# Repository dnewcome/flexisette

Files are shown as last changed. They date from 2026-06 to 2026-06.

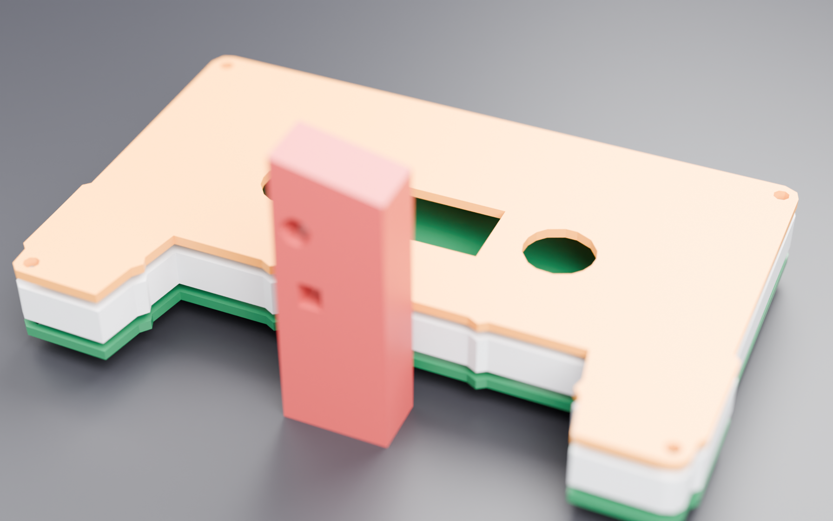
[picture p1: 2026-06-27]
render/out/flexisette_assembly.png

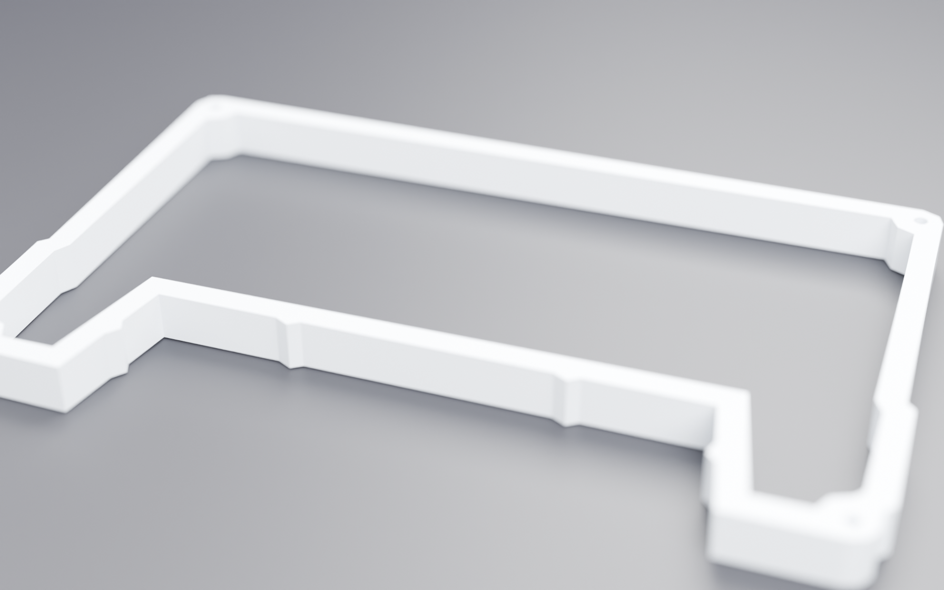
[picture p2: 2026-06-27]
render/out/flexisette_frame.png

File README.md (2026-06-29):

# flexisette

A **flex-PCB cassette-tape multimedia object** — a parametric, cassette-shaped board that plays its
own music with a tiny animated display where the tape window would be. Designed as reproducible
"drops": the whole thing regenerates from source (CAD, PCB, renders, firmware).

> Status: work in progress. The mechanical CAD and the PCB design are functional and fabbable; the
> on-device firmware is early.

## The idea

It's the size and shape of a compact cassette. A **0.96″ OLED** sits behind the cassette's central
**tape window** and plays a looping tape-winding animation — the one spot on a cassette where you
expect to see motion. An **ESP32-S3** plays the baked-in audio out a small speaker; it charges over
USB-C and runs off a LiPo.

| Block | Part |
|---|---|
| MCU | ESP32-S3-WROOM-1-N16R8 (native USB) |
| Display | 0.96″ SSD1306 OLED (I²C), in the tape window |
| Audio | MAX98357A I²S class-D amp → speaker |
| Power | USB-C → TP4056 charger → LiPo → ME6211 3V3 |

All parts are JLCPCB/LCSC-stocked for turnkey assembly.

## Repository layout

```
cad/        parametric CAD (build123d) of the physical parts — frame, panel, insert, spacer —
            extracted from real vendor cassette STLs; mate-based assembly + MuJoCo sim
pcb/        the electronics PCB, code-driven with tscircuit (modules/ -> index.circuit.tsx),
            finished in KiCad. Includes the encoded place->route->measure tooling (scripts/)
            and per-fab DRC rule files (rules/)
display/    the 128x64 tape-winding animation for the OLED (display/tape_anim.py)
render/     Blender product renders / .blend files
assets/     vendor cassette shell STLs the CAD is derived from (see assets/DOWNLOADS.md for sources)
specs/      design specs
PARTS.md    component sourcing / BOM notes
```

## Building

- **CAD:** `make` (or run the `cad/*.py` build123d scripts) → STL/STEP/FCStd in `cad/build/`.
- **PCB:** in `pcb/`, `npm install` then `make build` (tscircuit) → `index.circuit.kicad_pcb`; place
  with `make outline` / `make routecheck`, route with Freerouting (`make freeroute`) or in KiCad, and
  apply a fab rule set from `pcb/rules/`. The board outline is the real cassette face (derived from the
  same profile as the CAD).
- **Animation:** `python3 display/tape_anim.py` → a 128×64 GIF preview.

The PCB workflow follows the code-driven, placement-first approach (modular subcircuits, deterministic
placement, ground pours, then route) — see [docs/pcb-toolchain.md](docs/pcb-toolchain.md) and
[docs/workflows.md](docs/workflows.md).

## Documentation

Full documentation lives in **[`docs/`](docs/)** — start with
**[docs/architecture.md](docs/architecture.md)** for the big picture, then:

- [PCB toolchain](docs/pcb-toolchain.md) · [Placement (the fast loop)](docs/placement.md) ·
  [CAD enclosure](docs/cad-enclosure.md)
- [3D fit-check + renders](docs/3d-fit-and-renders.md) · [Fabrication (JLCPCB)](docs/fabrication.md)
- [Workflows — task recipes](docs/workflows.md) · [Reference — every target/script/artifact](docs/reference.md)
- [Roadmap & known issues](docs/roadmap.md) · [Planned placement constraints](docs/placement-constraints.md)

*Project started June 25, 2026.*

## License

TBD. Vendor cassette assets under `assets/` retain their original licenses — see
`assets/DOWNLOADS.md` for attribution.

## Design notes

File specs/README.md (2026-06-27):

# flexisette — Form-Factor Specs

Four construction options for the same product. They **share one frozen electrical engine** (see [`../PARTS.md`](../PARTS.md)) — what differs is the *physical build*. The discipline throughout: **freeze the electronics, vary the cosmetics + content**, so a "drop" is cheap.

> A cassette is **~100.5 × 64 × 12 mm**. The Norelco case + a paper (or flex) J-card is the package. The engine BOM is one line:
> ESP32-S3-WROOM-1-N16R8 · 1.91" RM67162 QSPI AMOLED · MAX98357A+speaker / PCM5102A+jack · microSD or W25Q512 · NTAG I²C plus · LP503562 1200mAh · MCP73831 + USB-C native.

## The four

| # | Name | Form | Boards | Thickness | Plays in a real deck? | Battery / runtime | Per-drop cost | Best for |
|---|---|---|---|---|---|---|---|---|
| [A](A-the-deck.md) | **The Deck** | full cassette | 2 rigid + 3D-printed spacers | ~12 mm | ✅ **yes** | 1200 mAh / ~7–9 h | medium | the full "it really plays in a tape deck" object |
| [B](B-the-slim.md) | **The Slim** | cassette outline | 1 rigid | ~5–7 mm | ✖ (needs a carrier) | 500 mAh / ~3 h | high (whole-board respin) | elegant ultra-thin PCB-as-art player |
| [C](C-the-flex.md) | **The Flex** | cassette, flex/rigid-flex | rigid islands + flex | thin–12 mm | partial | island-dependent | high fab | the most distinctive substrate; original "flex cassette" vision |
| [D](D-flex-jcard.md) | **The Flex J-card** | J-card insert | 1 plain flex | <0.5 mm folded | n/a (it's the insert) | none (or NFC-harvest) | **very low (~$1–3)** | the per-drop art/NFC layer — pairs with A/B/C |

## How they relate
- **A, B, C are mutually exclusive device bodies** — pick one to build.
- **D is not a competitor — it's the per-drop skin.** The flex J-card (D) is the cheap, swappable art + NFC + touch layer that any of A/B/C uses as its insert/front. It *is* the parametric mechanism; A/B/C are just how deep the electronics go behind it.
- **Recommended first build:** prototype the engine on a breadboard (the "first slice"), then realize it as **A (The Deck)** — it's the only one that delivers the tape-deck-playback payoff — with **D** as its art layer. B and C are alternate editions to explore later.

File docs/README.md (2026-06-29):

# flexisette documentation

Start with **[architecture.md](architecture.md)** for the big picture, then dive into a subsystem.

| Doc | What it covers |
|---|---|
| **[architecture.md](architecture.md)** | The whole system: the three subsystems (PCB / placement / CAD), the fit-check seam, the data flow, the four coordinate frames, the repo map, and the reproducibility principles. **Read first.** |
| [pcb-toolchain.md](pcb-toolchain.md) | The board: modular `<subcircuit>` architecture, the parts/nets/cutouts, and the tscircuit→KiCad place→route→IPC-inject pipeline (`route.sh` + helpers). |
| [placement.md](placement.md) | The fast early-design loop: positions-as-data, the `place`/`sync`/`variant` round-trip, the auto-untangle (rotation), block autoplace, the placement gates, and the planned constraint layer. |
| [cad-enclosure.md](cad-enclosure.md) | The 3D-printed cassette shell (build123d): the sandwich stack, `machine_params.py`, each part, the head insert + screw bosses, and the assembly. |
| [3d-fit-and-renders.md](3d-fit-and-renders.md) | The seam + the pictures: bare vs populated board into 3D, the coordinate transforms, the OLED model, the OpenSCAD fit-check, the GLB merge, and the Blender beauty render. |
| [fabrication.md](fabrication.md) | Gerbers + assembly BOM/CPL (`make fab`), uploading to JLCPCB, and what the DFM does/doesn't catch. |
| [workflows.md](workflows.md) | Task recipes — copy-paste commands for the common things (route, fab, variant, fit-check, render, see the files). |
| [reference.md](reference.md) | Exhaustive reference: every make target, every script, every generated artifact, every data-file format. |
| [roadmap.md](roadmap.md) | Known gaps + discrepancies + the (grounded) future-work directions. |
| [placement-constraints.md](placement-constraints.md) | Design (plan only) for the per-part lock / move / rotate constraint layer. |

## Orientation for a newcomer

- The object is a **cassette-shaped PCB** in a **3D-printed cassette shell**, with an OLED behind the
  tape window. It regenerates entirely from source — see *reproducibility principles* in
  [architecture.md](architecture.md).
- **PCB work** is in `pcb/` (run make targets from there); **mechanical CAD** is in `cad/` (run from the
  repo root). The two meet in the **3D fit-check** (`make fit`).
- If you just want to *see* the current design: `cd pcb && make show`, or `make fit` then open
  `cad/build/fit_iso.png`.
- If something says "where's the file?" — generated artifacts live in **gitignored `build/`/`dist/`/`fab/`**
  dirs (real files, not committed); the map is in [reference.md](reference.md).

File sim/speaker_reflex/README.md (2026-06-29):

# speaker_reflex — sealed face-firing micro-speaker sim

Thiele-Small lumped **acoustical equivalent circuit** of the flexisette speaker. The design (decided):
a slim **face-firing micro-driver** in a **sealed** back-volume carved from the cassette interior — the
cassette is only 9mm thick, so a forward-firing driver through the head slot doesn't fit; lying flat and
firing out the face does. (The model still supports a vented port; we A/B'd it and chose sealed.)

The enclosure *is* the model: the box is an acoustic compliance `Cab = Vb/ρc²`. ngspice solves the
circuit; an independent numpy complex-impedance solve verifies the deck.

```
python3 reflex.py        # -> sealed.png (SPL vs Vb, excursion, Fc&Qtc vs Vb, impedance), reflex.cir
```

**Driver: PUI Audio AS01808AO** (18×13mm, 3mm thick, 8Ω, 1W). `Fs=320 Hz` and impedance are PUBLISHED;
`Sd, Vas, Qts, Xmax` are **ESTIMATED from the cone size — measure before finalizing** (a DATS, or a DIY
two-resistor impedance sweep on the board's own amp). The whole "boomy vs flat" question hangs on Qts.

## Verification
- sealed ngspice vs analytic |Ud|: **0.00 %**.
- sealed impedance = single hump (vs the vented twin-hump we confirmed earlier).

## Findings (AS01808, estimated Vas/Qts)
1. **The real driver's low Fs (320 Hz) drops the box knee to ~450–550 Hz** — a genuine low-mid lift,
   far below the 1.1 kHz of the pessimistic placeholder. Sealed in the cassette gives real low-mids.
2. **Qtc is high (~1.3–2.0)** with the estimated `Qts=1.0` → a resonant **peak/boom at Fc**, not a flat
   response. The *real* Qts decides whether that's a pleasant bump or a one-note boom — **measure it.**
   If it's high, a touch of stuffing (raises effective Vb, lowers Qtc) or a lower-Qts driver tames it.
3. **More back-volume always helps** (lower Fc *and* lower Qtc) — `Fc 640→413 Hz` and `Qtc 2.0→1.3` as
   `Vb 4→18 cm³`. **Carve as much interior as possible** (~10–12 cm³ → Fc ~450 Hz); diminishing past that.
4. **Excursion-limited, not power-limited:** ~0.7 mm @1W vs ~0.35 mm Xmax → ~**250 mW clean → ~70 dB@1m**.
   The MAX98357A has headroom the micro driver can't use. (Absolute SPL is uncertain on estimates.)

## Next
- **Measure the AS01808's T-S** (Qts especially) and re-run → lock the response / decide if stuffing is
  needed. The DIY rig: drive the driver through a known series R off the board's amp, log V across each,
  derive Z(f) → Fs, Qts (added-mass trick for Vas).
- **CAD the sealed chamber** (build123d) behind the face-firing driver, sealing as much cassette
  interior as the PCB/battery allow as back-volume; the driver lies flat (3mm) under a grille.

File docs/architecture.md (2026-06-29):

# flexisette — architecture

How the whole thing fits together. Start here; the subsystem docs go deep.

## What it is

flexisette is a **flex-PCB cassette-tape multimedia object**: a board the size and shape of a compact
cassette that plays its own baked-in music out a small speaker while a 0.96″ OLED animates where the
tape window would be. ESP32-S3 brain, USB-C charging, LiPo power. It lives inside a **3D-printed
cassette shell**, and the OLED glows through the shell's central window.

**North star — reproducible "drops":** the entire object regenerates from source. The circuit, the
board placement, the routing inputs, the enclosure parts, the fab outputs, and the renders are all
produced by code + data in this repo. Shipping a different version is editing data, not redrawing.

## The three subsystems + the seam

```
        ┌──────────────────────────────┐        ┌──────────────────────────────┐
        │  PCB  (electronics)          │        │  CAD  (mechanical)           │
        │  code-driven, pcb/           │        │  parametric, cad/            │
        │                              │        │                              │
        │  tscircuit .tsx  ──► KiCad   │        │  build123d .py  ──► STL/STEP │
        │  generate + place   route    │        │  shell: frame/panel/insert/  │
        │                              │        │         spacer  +  assembly  │
        └───────────────┬──────────────┘        └───────────────┬──────────────┘
                        │                                        │
                        │     shared geometry: cassette outline, │
                        │     tape window, 2 reels, 4 screw holes │
                        ▼                                        ▼
              ┌─────────────────────────────────────────────────────────┐
              │  SEAM: the 3D fit-check  (cad/import_pcb + render_fit)   │
              │  bring the routed board INTO the printed-part assembly,  │
              │  co-register, render, gate placement on alignment       │
              └─────────────────────────────────────────────────────────┘
                        │
                        ▼
        ┌──────────────────────────────┐        ┌──────────────────────────────┐
        │  Firmware (display/, early)  │        │  Outputs                     │
        │  tape-winding animation      │        │  fab (gerbers/BOM/CPL),      │
        │  on the SSD1306              │        │  renders (OpenSCAD + Blender)│
        └──────────────────────────────┘        └──────────────────────────────┘
```

- **PCB** — [pcb-toolchain.md](pcb-toolchain.md): tscircuit (React/TSX) *generates + places* the board
  from code; KiCad *routes* it (the autorouter via Freerouting, injected back over the IPC API). The
  north-star belief is **routing difficulty is set by placement**, so the effort goes into placement.
- **Placement** — [placement.md](placement.md): the fast early-design loop. Positions live as **data**
  (`pcb/placement/<variant>.json`), round-trip between KiCad and the source, get auto-untangled by a
  rotation pass, and drive per-release **variants**.
- **CAD enclosure** — [cad-enclosure.md](cad-enclosure.md): the printed cassette shell as a build123d
  sandwich (PCB-half + spacer + PCB-half ≈ 9 mm), with the head-access insert, screw bosses, and the
  window/reel/screw features that must line up with the board.
- **3D fit + renders** — [3d-fit-and-renders.md](3d-fit-and-renders.md): the seam. Export the board to
  3D (bare KiCad STL or populated tscircuit GLB), seat it in the shell assembly, render the fit-check
  (OpenSCAD) or a beauty shot (Blender). The OLED — which has no CDN 3D model — is modeled here.
- **Fabrication** — [fabrication.md](fabrication.md): Gerbers + drill + assembly BOM/CPL for JLCPCB, and
  what their DFM does and doesn't catch.
- **Reference** — [reference.md](reference.md): every make target, script, artifact, and data file.
- **Workflows** — [workflows.md](workflows.md): task recipes. **Roadmap + known issues** —
  [roadmap.md](roadmap.md). **Planned constraint layer** — [placement-constraints.md](placement-constraints.md).

## Data flow (source → object)

```
SOURCE (committed)                 GENERATED (gitignored build/)        OUTPUT
─────────────────                  ────────────────────────────         ──────
pcb/*.circuit.tsx  ──tsci export──► pcb/index.circuit.kicad_pcb ──route──► fab/  (gerbers, BOM, CPL)
pcb/placement/*.json ──apply──────►  (placement on the board)
                                    pcb/build/3d/*.glb,*.step   ─────────► glTF viewers
cad/*.py           ──build123d────► cad/build/*.stl, *.step    ──render──► cad/build/fit_*.png  (OpenSCAD)
                                                               ──render──► render/out/*.png     (Blender)
```

Everything in `build/`, `dist/`, `fab/` is **regenerated, gitignored, never committed** — real files on
disk you can open, just not in git. The committed source of truth is the `.tsx`, the `.py`, the
`placement/*.json`, and `lib/*.json`. See [reference.md](reference.md) for the full artifact map.

## Coordinate frames (the thing that bites)

Four frames are in play; conversions are the subtle part (full detail in
[3d-fit-and-renders.md](3d-fit-and-renders.md) and [placement.md](placement.md)):

| Frame | Origin / up | Notes |
|---|---|---|
| **tscircuit** (design) | board-centred, **Y-up** | the `.tsx` `pcbX/pcbY`; window at (0, +3) |
| **KiCad** (`.kicad_pcb`) | offset to ≈(100,100), **Y-down** | `tx = kx−100, ty = 100−ky` |
| **cad / OpenSCAD** | board-centred, **Z-up** | build123d parts; fit render frame |
| **glTF (GLB)** | board-centred, **Y-up** (thickness=Y) | tscircuit (x,y) → GLB (x, −z) |

The board-outline bbox centre is what reconciles tscircuit↔KiCad (it's at (100,100) for this board).
KiCad→cad needs a **Y-mirror**; cad→GLB needs a **−90° rotation about X**.

## The repository

```
flexisette/
  README.md, PARTS.md          project overview + bill of materials
  Makefile                     top-level: CAD builds + Blender renders
  cad/                         parametric cassette shell (build123d) + the 3D fit-check + OLED model
  pcb/                         the tscircuit board, its scripts, Makefile, placement data, fab outputs
    modules/                   the functional blocks (mcu/power/audio/display) as <subcircuit>s
    scripts/                   the place→route→fab pipeline (route.sh + the helpers)
    lib/, imports/             fab params, helpers, imported JLC parts, cassette outline/holes JSON
    placement/<variant>.json   positions-as-data (the round-trip floorplan)
    tests/                     unit tests for the placement tooling (autoplace, untangle)
  render/                      Blender beauty-render pipeline (needs a GPU box)
  display/                     firmware-side OLED animation (early)
  docs/                        this documentation set
  assets/                      vendor cassette-shell source files (STL/PDF)
```

## Reproducibility principles

1. **Generate, don't draw.** The board comes from `.tsx`; the shell from `.py`. No hand-placed XML.
2. **Positions are data.** The floorplan lives in `placement/<variant>.json`, round-tripped from KiCad
   — so a layout is reproducible and a *variant is a different data file*, not a forked circuit.
3. **One source of truth per dimension.** `cad/machine_params.py` holds every shared shell dimension;
   parts derive from it. (Caveat: a few values have drifted — see [roadmap.md](roadmap.md).)
4. **The fit-check is a gate, not a picture.** Connector/cutout/screw alignment between board and shell
   is verified in 3D and treated like a DRC rule.
5. **Tools over heroics.** Routing is hard, so design for trivial routing (modular blocks, ground
   pours, deliberate placement, auto-untangle) and hand-finish the tail.

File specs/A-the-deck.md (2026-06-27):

# Spec A — "The Deck" (full-size, 2 rigid boards + 3D-printed spacers)

**One-liner:** A full cassette-dimensioned device — two rigid PCBs sandwiched around a 3D-printed internal frame — that is self-contained *and* can be dropped into a real tape deck and played.

This is the maximal version: most capable, biggest battery, and the only build that delivers the **plays-in-a-real-deck** payoff.

## Dimensions / stack-up
Target envelope: **100.5 × 64 × 12 mm** (compact-cassette nominal). The 12 mm Z budget, front to back:

```
 front board (1.0–1.6 mm) + display module (~2–3 mm, recessed behind window)
 ── 3D-printed spacer frame ── (houses LiPo 5 mm + transmit head + auto-stop gear)
 main board (1.6 mm)
                                              ≈ 11–12 mm total
```

## Boards
- **Front board (per-drop candidate):** display window + AMOLED mount, capacitive-touch pads / tactile buttons, status LEDs, top-copper J-card-style art, speaker grille. Can be a cheap cosmetic respin per drop — *or* leave it minimal and push art onto a flex J-card (Spec D).
- **Main board (frozen engine):** ESP32-S3, audio (MAX98357A + PCM5102A), storage, charger + power, USB-C (native), NFC (NTAG I²C plus), the **tape-head driver amp**, and the board-to-board connector.
- **Interconnect:** Hirose DF40 mezzanine (0.4 mm, pick stack height to fit) or a short FFC between the two boards.

## 3D-printed spacer parts (the heart of this spec)
A printed frame does five jobs at once:
1. Holds the two boards at correct spacing and registration (standoffs/snap features).
2. **LiPo pocket** (LP503562, 5 mm) in the central cavity.
3. **Bottom-edge cassette geometry** — head-access window, capstan holes, pinch-roller cutouts, alignment/registration boss, write-protect notches — so it **loads and seats in a real deck** and in the Norelco case.
4. **Transmit-head mount** at the head window (from a harvested adapter head — see PARTS §11), sprung to the right contact height.
5. **Auto-stop defeat** — a capstan-driven dummy-hub gear so the deck doesn't stop on "no tape motion." (Harvest this whole mechanism from the donor adapter.)

## Tape-deck playability — ✅ yes
This is the variant designed for it. The same audio engine has three output destinations: onboard speaker (MAX98357A), 3.5 mm jack (PCM5102A), and the **transmit head** (line-out → small amp → head). Mono, lo-fi, on-brand.

## Drops / parametric story
Frozen main board + frozen engine BOM. Per drop you vary: the **flex J-card / front-board art**, the **content pack** on storage, and optionally reprint the **spacer** for shape tweaks. The expensive board never respins.

## Pros / cons
- ➕ Most capable; ~7–9 h battery; real-deck playback; room for a speaker cavity; robust.
- ➖ Thickest/heaviest; most parts; two-board assembly; 3D-print tolerances on the bottom-edge mechanism are the fiddliest engineering.

## Open risks
- Auto-stop gear + head alignment precision (mitigated by harvesting the donor adapter's mechanism wholesale).
- Z-budget is tight — verify display + LiPo + both boards actually close to ≤12 mm before committing.
- Magnetic neighbors: keep the transmit head and NFC coil away from the LiPo.

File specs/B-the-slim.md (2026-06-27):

# Spec B — "The Slim" (single ultra-thin board, cassette profile)

**One-liner:** One rigid PCB cut to the cassette outline, made as thin as physically possible — "a circuit board that happens to be cassette-shaped." An object you display, not a gadget you operate.

This is the elegant, minimal version. It trades capability and deck-compatibility for thinness and a pure PCB-as-art read.

## Dimensions / stack-up
Outline: cassette silhouette **~100 × 64 mm**; usable copper ~98 × 62 mm. Thin:

```
 display module (~2 mm, front)
 single PCB (1.0–1.6 mm) — all components on the back, low-profile SMD
 thin LiPo (~3–4 mm) in a back pocket / adhered
                                              ≈ 5–7 mm total  (half a cassette)
```

## Board
A single board carries everything: ESP32-S3, AMOLED, audio, NFC coil along an edge, USB-C, storage. **Likely no onboard speaker** (no cavity at this thickness) — favor a 3.5 mm jack and/or the transmit head, or a bone-conduction exciter (#1674) using the case as a diaphragm.

## Battery
Smaller, thinner cell — LP503035 500 mAh (~3 h) or a custom thin pouch. Runtime is the main casualty of thinness.

## Tape-deck playability — ✖ (not natively)
At 5–7 mm it won't seat/load in a deck. If wanted, add an optional **3D-printed cassette-thickness carrier shell** the slim board drops into — but that's bolting on Spec A's idea; not this spec's purpose.

## Drops / parametric story
The catch: it's all *one board*, so a per-drop change = a **full board respin** (more than a cosmetic-only respin). Mitigate by freezing component placement and varying only **soldermask + silkscreen + copper-art layers** + the content pack. Or pair with a flex J-card (Spec D) so the *art* lives on the cheap swappable insert and the slim board stays visually constant.

## Pros / cons
- ➕ Thinnest and most elegant; cheapest assembly (single board, single-sided); strongest PCB-as-art statement; can ship as a bare beautiful object.
- ➖ Small battery; no speaker cavity; doesn't work in a deck without a carrier; per-drop board respin is the priciest parametric path of the four.

## Open risks
- Thin LiPo sourcing + runtime acceptability.
- Single-board respin economics for frequent drops — lean on Spec D to keep drops cheap.
- Component height: everything must stay low-profile to hold the ~5–7 mm target.

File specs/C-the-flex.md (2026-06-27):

# Spec C — "The Flex" (flex / rigid-flex construction)

**One-liner:** The device built *on* flex — rigid islands carry the silicon, flex carries the shape, art, antenna, and touch. The most literal realization of the original "a flex PCB that looks like a cassette" vision.

## Construction
**Rigid-flex:** 2–3 rigid islands (an **MCU/audio island**, a **display island**, a **power/battery island**) joined by flex. Two sub-modes:

- **C1 — Folded:** the flex folds the rigid islands on top of each other into the 12 mm cassette envelope (origami-style). Gets a multi-layer stack **with no board-to-board connectors** — the flex *is* the interconnect.
- **C2 — Flat:** a cassette-shaped flexible *sheet* with electronics on islands and the silhouette/art across the flex. The closest thing to "a cassette made of circuit board" — thin, conformable, a flat object (a cassette-shaped card).

The NFC antenna coil, cap-touch electrodes, and LED art integrate natively into the flex regions (free copper).

## Battery
Keep the LiPo on a **rigid island**, never on bare flex (flex + battery = cracked joints). LP503562 in C1-folded; a thinner cell for C2-flat.

## Tape-deck playability
- C1-folded: possible with a printed spacer (like Spec A), but cramped.
- C2-flat: no.

## Drops / parametric story — the catch
Rigid-flex is **expensive at low volume (~5–10× plain flex + connector)**. Respinning it per drop kills the parametric economics. So even here: **freeze the rigid-flex**, and push per-drop art onto a separate cheap **plain-flex J-card (Spec D)**. The rigid-flex is the *body*; D is the *skin*.

## Pros / cons
- ➕ Most distinctive; antenna/touch/art baked into the substrate; can be very thin; no inter-board connectors (C1).
- ➖ Highest fab cost; harder to design + assemble; flex fatigue if any region is repeatedly flexed (design folds as fold-*once*); battery must stay on a rigid island.

## Open risks
- Rigid-flex cost vs. drop quantity — likely only worth it for a flagship/premium edition.
- Stack-up + bend-radius engineering (minimum inside radius, copper-free bend zones).
- This is the highest-complexity build of the four — not the first one to attempt.

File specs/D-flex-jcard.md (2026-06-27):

# Spec D — "The Flex J-card" (pre-creased flex insert that replaces the paper J-card)

**One-liner:** A plain flex PCB shaped and pre-creased like a J-card — the per-drop swappable art + interface + NFC surface. It replaces the paper insert and folds reliably into a Norelco case. **This is the core parametric mechanism**, and it pairs with any device body (A/B/C).

## Geometry
A J-card unfolds to a strip ~63 mm tall (just under cassette height), folded at two lines into a "J":

```
 ┌───────────────────────────┬──────┬─────────┐
 │  FRONT PANEL ~100 mm wide │SPINE │ TUCK    │   height ≈ 63 mm
 │  (art / display window /  │~12mm │ FLAP    │
 │   touch / LEDs)           │      │ ~15 mm  │
 └───────────────────────────┴──────┴─────────┘
        fold line 1 ↑            fold line 2 ↑
```
*(Verify exact panel dims against a physical Norelco case before fab.)*

## What it carries
- Copper / silkscreen / **ENIG-gold** art — the liner-note aesthetic, *as the board*.
- Capacitive-touch pads (the polyimide coverlay is the touch dielectric — free).
- LEDs back-lighting the art through the coverlay.
- **NFC antenna coil** (single-layer, over a ferrite film, away from the LiPo, with a C0G trim-cap footprint).
- Optional display window / cutout; optional FFC tail to the engine.

## Two roles
- **D1 — Smart liner card (standalone):** NFC-only (NTAG / NTAG I²C plus), no wire to the engine. A gorgeous insert that taps to the drop's web experience. Works as the package for **any** of A/B/C. Cheapest, purest art + NFC.
- **D2 — Interface skin:** plugs into the engine via the 0.5 mm FFC/ZIF and becomes the device's touch/LED/art front. This is the per-drop "Board B."

## Pre-creasing — the manufacturing question
Flex is **elastic** — it won't take a crisp permanent crease like paper. Reliable approaches, cheapest first:
1. **Defined bend areas + case retention (recommended):** at each fold line keep copper out (or run only perpendicular, hatched/curved traces), single-layer in the bend, coverlay bend-relief; inside bend radius ≥ ~6–10× material thickness. The flex *wants* to fold there; the **Norelco case holds it folded**. Cheap on plain JLCPCB/PCBWay flex.
2. **Laser-score / half-etch the polyimide** at the fold so it takes a set — possible, but risks cracking copper; keep copper well clear of the score line.
3. **Rigid-flex panels + flex hinges (premium):** discrete rigid art panels joined by flex hinge strips fold flat *and stay flat* — the most reliable "pre-creased" feel, but priced like rigid-flex.

**Recommendation:** defined bend areas + case retention for normal drops; reserve rigid-flex hinges for a premium edition. Specify the bend regions explicitly in the fab notes, and stiffeners only where the FFC contacts/connector sit.

## Drops / parametric story
**This is the cheapest per-drop artifact of everything** — plain flex ~$1–3/unit at 50–100, fully art-variable, optional NFC per drop, hand-swappable via the ZIF. The whole "limited-run drops" concept rides on this layer.

## Open risks
- Fold reliability vs. cost (bend-area design + case retention is the sweet spot).
- NFC coil keep-out from the LiPo + copper pours (needs ferrite; see PARTS §6).
- Registration of the display window / touch pads to the engine behind it.

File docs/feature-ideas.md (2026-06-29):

# flexisette — feature ideas (product-level TODO)

Cross-cutting features (mechanical + electrical + firmware), distinct from the PCB
[roadmap.md](roadmap.md) (which is about finishing the *current* board). Each is captured enough to
pick up later; status notes whether it's being designed now or parked.

---

## Tape-deck playback — hub-encoder speed sync + head-emulation coil  *(planned — design later)*

**The vision:** drop the flexisette into a *real* cassette deck and "play" it — the deck spins the
hubs and reads a head, and the cassette behaves like a magnetic tape, **speed-coupled to the deck's
transport.** Play / FF / REW / pause on the deck would control the audio.

Two subsystems make it work:

1. **Head-emulation coil (the cassette-adapter trick, in reverse).** A small coil sits in the insert at
   the exact spot a deck's playback head contacts the tape (the head-gap window). The ESP32 drives the
   coil with the audio signal so it **induces flux into the deck's own playback head** — the deck then
   plays the flexisette's audio through its normal electronics + speakers. (This is how Bluetooth/aux
   "cassette adapters" couple into a deck, run backwards: we emit instead of receive.)

2. **Hub-rotation encoder (the speed-control novelty).** An encoder reads the **reel/hub spin** — the
   deck's reel drive turns the hubs as if it were winding tape. The ESP32 **syncs the playback rate to
   the measured hub speed + direction**, so the deck's transport drives the audio: normal speed on play,
   fast/garbled on FF/REW, stop on pause, even reverse. Effectively the flexisette *is* the tape.

**Why it's worth it:** it turns the object from "a board that plays a clip" into "a cassette that any
deck can play," with authentic transport feel — a strong demo and a real differentiator.

**Open design questions (for the later pass):**
- *Encoder:* reflective-optical on a patterned hub vs. a hall sensor + magnet on the hub vs. a printed
  quadrature pattern. Resolution needed for smooth speed; **direction** sensing (quadrature) is required
  for REW.
- *Head coil:* turns / core / footprint / exact position to couple into a standard head gap; the drive
  path (DAC → coil driver, or a small audio transformer); output level vs. a real tape's flux; whether
  to apply tape **playback EQ** (NAB/IEC) so it sounds right through the deck.
- *Mechanical:* the coil embedded in the **insert** at the head-contact line; the encoder at a **reel
  hub**; the hubs must be **free-spinning** and engage the deck's reel drive (today's reels are cutouts —
  they'd become real rotating hubs).
- *Firmware:* resample stored audio to the hub-derived clock; handle stop / reverse / wow-and-flutter;
  a control loop from hub-tachometer → playback rate.
- *Interplay with the rest:* the reels (currently board cutouts) become moving parts; the insert gains
  the coil; this competes for the same insert volume as the **bass-reflex speaker** below — they may
  need to share or trade the insert space.

---

## Bass-reflex micro-speaker in the head insert  *(in design now)*

A tuned micro-enclosure in the ~6–8 cm³ head-insert region: a **slim oval driver firing through the
24×6 mm head-access slot**, with a **folded/labyrinth port** to extend the low end. At this volume the
tuning lands in the low-mids (~300–500 Hz), not true bass — but far fuller/louder than a bare
micro-speaker. Approach: model the driver + box + folded port as a Thiele-Small equivalent circuit in
ngspice (the **circuit-sim** skill), tune it, then CAD the enclosure into the insert (build123d).
*Note the contention with the head-emulation coil above for the same insert volume.*

---

## Parking lot (one-liners, unplanned)
- Multi-device / sync play across several flexisettes (the original brief mentioned multi-device).
- A simple game / interaction on the OLED + the two tact buttons.

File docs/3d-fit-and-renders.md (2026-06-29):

# 3D fit-check and render pipelines

This subsystem is the mechanical seam between the **routed PCB** (KiCad / tscircuit) and the
**3D-printed cassette parts** (build123d). It does two jobs:

1. **Fit-check** — bring the real board into the printed-part assembly, co-register both on a
   shared datum, and render the stack so that connector / cutout / screw / window alignment can be
   read by eye. Alignment is treated as a *placement gate*: a connector or the OLED window is only
   in the right place on the board if it lines up with the matching opening in the shell.
2. **Beauty renders** — Blender/Cycles hero shots of the full assembly for the README / devlog.

It implements the [`pcb-enclosure-fit`](../../.claude/skills/pcb-enclosure-fit/SKILL.md) skill for
this project. The north star from that skill: *a board and its enclosure are ONE design — connector,
cutout, and screw positions only exist correctly if they line up in 3D. Params lie; the rendered
overlay does not.* This doc covers the flexisette-specific wiring of that idea.

Repo root: `/home/dan/sandbox/dnewcome/flexisette`. All scripts here live under `cad/` and
`render/`; the driving Make targets live in `pcb/Makefile`.

---

## The loop at a glance

```
route board ──▶ kicad-cli export step ──▶ import_pcb.py ──▶ render_fit.py ──▶ eyeball overlay
     ▲              tsci export -f step      (pcb.stl /        (fit_iso/top/pop)      │
     │                                        pcb_pop.stl)                            │
     └──────────── nudge connector/display placement to the shell openings ◀─────────┘
```

Run the whole loop after each place/route pass:

```bash
cd pcb && make fit      # import both board sources + model the OLED + render the 3 fit views
cd pcb && make show     # open fit_top.png + fit_iso.png and print the 3D/GLB/STL paths
```

`make fit` expands to (`pcb/Makefile`):

```make
fit:
	python3 ../cad/import_pcb.py index.circuit.kicad_pcb    # bare routed board (layer registration)
	python3 ../cad/import_pcb.py index.circuit.tsx          # populated board (component bodies)
	python3 ../cad/oled.py                                  # OLED module (no CDN 3D model — modeled here)
	python3 ../cad/render_fit.py 6
```

> The printed parts themselves (`frame.stl`, `panel.stl`, `insert.stl`) are produced by the
> top-level `Makefile` (`make cad`) from build123d; the fit loop consumes them, it does not build
> them. If `cad/build/` is empty, run `make cad` from the repo root first.

---

## Coordinate frames (get this right or nothing aligns)

There are four frames in play. Co-registration is the one thing the whole subsystem hinges on.

| Frame | Up axis | Origin | Notes |
|---|---|---|---|
| **KiCad** (`*.kicad_pcb` STEP) | Z-up, **Y-down** (screen) | arbitrary; for this board the Edge.Cuts bbox centre is **(100, 100) mm** | needs a Y-mirror to enter the cad frame |
| **tscircuit** (`*.tsx` STEP/GLB) | Z-up, **Y-up**, origin-centred | (0, 0) | already in the cad convention; no mirror |
| **cad / OpenSCAD** (build123d, `render_fit.py`) | **Z-up**, Y-up | cassette centre | the working frame for the fit stack |
| **glTF / GLB** | **Y-up** | scene | tscircuit `(x, y)` → GLB `(x, −z)`; bottom layer at `Y < 0` |

### KiCad → cad transform

`import_pcb.py` co-registers by **bbox-centre**, computed live from the imported solid:

```python
bb = s.bounding_box()
cx, cy = (bb.min.X + bb.max.X) / 2, (bb.min.Y + bb.max.Y) / 2
s = Pos(-cx, -cy, -bb.min.Z) * s     # center XY, drop lowest point to z=0
if not populated:
    s = mirror(s, Plane.XZ)          # KiCad Y-down -> cad Y-up
```

For flexisette the Edge.Cuts bbox centre is exactly **(100, 100) mm** in the KiCad frame, so the
net mapping from a KiCad coordinate `(kx, ky)` to the cad frame `(tx, ty)` is:

```
tx =  kx - 100
ty =  100 - ky      # the minus is the Y-mirror; without it the head/front edge and every
                    # asymmetric cutout (the head notch, the off-window OLED) land on the wrong side
```

The centre is *derived from the live bounding box*, not hard-coded — it just happens to be (100, 100)
because that is where tscircuit's KiCad export lands this outline. The mirror is the load-bearing
part: verify it by a known asymmetric feature (the bottom-centre head notch must stay at the front
edge `−Y`).

The tscircuit STEP is already centred and Y-up, so the `mirror` step is **skipped** for `.tsx`
sources.

---

## Two board-into-3D sources — `cad/import_pcb.py`

One script, two paths, dispatched on the source file extension. Both center the result on the
cassette origin and drop the board's lowest point to `z = 0`.

| | `*.kicad_pcb` source | `*.tsx` source |
|---|---|---|
| Exporter | `kicad-cli pcb export step --subst-models --no-dnp` | `tsci export -f step` |
| What you get | **ROUTED but BARE** — outline + every cutout + drill barrels. tscircuit footprints carry no *KiCad* 3D models, so there are no component bodies. | **POPULATED** — ~30 `cad_component` bodies (USB-C, ESP32, amp, generic passives) with real EasyEDA/JLCPCB models pulled from `modelcdn.tscircuit.com`. |
| Frame | KiCad Y-down → **mirror `Plane.XZ`** | already centred + Y-up → **no mirror** |
| Output | `cad/build/pcb.stl` | `cad/build/pcb_pop.stl` |
| Best for | **layer registration** — a clean flat plate to check outline / cutouts / screws against the frame | **connector / display protrusion + clearance** vs the shell openings |
| Caveats | `kicad-cli` returns **nonzero on benign warnings** — the STEP is still written; the code trusts the *file*, not `$?`. | needs **network** (CDN fetch); a `<copperpour>` throws a benign async warning during 3D render; `tsci` **mangles an absolute `-o`**, so the script writes `build/_pop.step` relative to `pcb/` and reads it back. Reflects tscircuit **placement, not KiCad routing** (fine for mechanical fit). |

Invoke directly:

```bash
python3 cad/import_pcb.py ../pcb/index.circuit.kicad_pcb   # bare, for the stack -> pcb.stl
python3 cad/import_pcb.py ../pcb/index.circuit.tsx         # populated, for bodies -> pcb_pop.stl
```

For the bare board the script also prints an **outline-vs-shell delta** so param drift gets caught:

```python
dx = b.size.X - M.SHELL_W
print(f"  outline vs shell {M.SHELL_W}x{M.SHELL_H}: "
      f"{'MATCH' if abs(dx) < 1 else f'dX={dx:+.1f}mm overhang'}")
```

> **Live drift (2026-06-28):** the routed outline is **102.24 mm** wide against `SHELL_W = 100.5`,
> so `import_pcb.py` currently reports **`dX=+1.7mm overhang`**. This is exactly the failure mode the
> skill warns about — a param can't catch a geometry that disagrees with it. Reconcile in
> `machine_params.py` (or the board outline), do not leave the render to keep re-flagging it.

The intermediate STEP for the KiCad path is written to `/tmp/_pcb_fit.step`.

---

## The OLED model — `cad/oled.py`

Neither tscircuit nor KiCad ships a 3D model for the 0.96" SSD1306 module (it has no CDN model), so
the fit/render pipeline models it from scratch as a prop. It mounts on the **back** of the board with
the screen facing out through the tape-window cutout.

Two STLs are emitted so the renderers can colour the dark screen separately from the blue module:

| STL | Contents | Colour role |
|-----|---|---|
| `cad/build/oled.stl` | module PCB + 4-pin header (`module()`) | blue module body |
| `cad/build/oled_screen.stl` | glass + 128×64 active area (`screen()`) | near-black glass |

Key dimensions (`oled.py` constants, mm):

| Const | Value | Meaning |
|---|---|---|
| `MOD_W, MOD_H, MOD_T` | 27.0, 27.0, 1.2 | module PCB (matches the 27×27 silk body) |
| `GLASS_W, GLASS_H, GLASS_T` | 25.5, 16.5, 1.4 | display glass |
| `ACT_W, ACT_H, ACT_T` | 21.7, 10.9, 0.3 | 128×64 lit rectangle |
| `HDR_W, HDR_H, HDR_T` | 10.5, 2.6, 2.6 | 4-pin header at the `−Y` edge, on the back (`−Z`) |

**Origin convention:** the module is centred in XY; the **back of the module is at `z = 0`**; the
**screen is on the `+Z` face**. So it is placed screen-up *behind* the board, and the header sits at
the `−Y` edge where it solders.

```bash
python3 cad/oled.py    # -> cad/build/oled.stl + cad/build/oled_screen.stl (prints bbox + watertight)
```

In the render frame the module is seated at the tape-window centre **`WIN = (0, 3)`** (the board
cutout and the cad assembly share this point).

---

## The OpenSCAD fit-check — `cad/render_fit.py`

This is the always-available previewer (OpenSCAD renders headless anywhere; Blender is the beauty
shot). It stacks the **real** board STLs with the printed parts at the `machine_params` Z datums and
emits three PNGs.

### Z datums (from `machine_params.py`)

```
PCB_T      = 1.57                       # each board / panel half
CASSETTE_T = 9.0                        # nominal shell thickness
SPACER_GAP = CASSETTE_T - 2*PCB_T = 5.86   # frame thickness, derived
TOP_Z      = PCB_T + SPACER_GAP   = 7.43    # top-layer datum
SHELL_W, SHELL_H = 100.5, 64.0
```

### Layer stack (`render_fit.py` `LAYERS`)

| STL | Z (mm) | Colour | Explode factor | Role |
|-----|---|---|---|---|
| `pcb.stl` | 0.0 | green | **−1.0** | real routed board (bottom) |
| `frame.stl` | `PCB_T` = 1.57 | grey | 0.0 | printed spacer frame |
| `panel.stl` | `TOP_Z` = 7.43 | warm orange | **+1.0** | printed top panel |
| `oled.stl` / `oled_screen.stl` | `0 − 4 − 2·explode` | blue / near-black | (explodes down) | OLED behind the board at `WIN = (0, 3)` |
| `insert.stl` | `z = PCB_T`, `y = −SHELL_H/2` (= −32), `rotate([90,0,0])` | maroon | — | head insert at the front edge |

The explode model is `z + ef*explode`: the board pulls down, the panel pushes up, the frame stays
put, and the OLED drops further below the board (`−4 − 2·explode`) so it reads apart. The `explode`
argument defaults to **6.0 mm** (`render_fit.py 6` in `make fit`); pass `0` for a closed stack.

Insert orientation in this quick stack is **cosmetic** for the alignment check — the load-bearing
read is the board-cutout ↔ shell-opening overlay, not the prettiness of the insert.

### The three views

| Output | Function | Camera (`x,y,z,rotx,roty,rotz,dist`) | Explode | Reads |
|---|---|---|---|---|
| `cad/build/fit_iso.png` | `render("iso", …)` | `0,0,0,58,0,22,420` | 6.0 | exploded iso — layers apart, board cutouts vs frame |
| `cad/build/fit_top.png` | `render("top", …)` | `0,0,0,0,0,0,420` | 0.0 | straight top-down — window / reels / screw alignment, OLED through the window |
| `cad/build/fit_pop.png` | `render_pop()` | `0,0,0,62,0,25,400` | n/a | **populated** board (`pcb_pop.stl`) with the frame ghosted (`%`) — connector / display protrusion + clearance |

All views render via:

```bash
openscad -o <out.png> --imgsize=1200,800 --colorscheme=Tomorrow \
         --camera=<cam> --autocenter --viewall <scene.scad>     # $fn=48
```

`render_pop()` quietly skips itself if `pcb_pop.stl` is absent, and every layer skips if its STL is
missing — so a partial `cad/build/` still renders what it can.

```bash
python3 cad/render_fit.py            # explode = 6.0 (default)
python3 cad/render_fit.py 0          # closed stack
```

---

## The GLB merge — `cad/merge_oled_glb.py`

`tsci export -f glb` bakes in the 30 CDN component models but **omits the SSD1306** (no model
exists). This script drops the modeled OLED STLs into that GLB at the tape window, behind the board,
and writes a combined GLB you can open in any glTF viewer.

The transform handles the cad-Z-up → glTF-Y-up frame change:

```python
# GLB frame is Y-up: tscircuit (x,y) -> GLB (x,-z); bottom layer is Y<0.
# Our STL is build123d Z-up (screen on +Z) -> rotate -90deg about X (screen -> +Y),
# then seat the screen just under the board (y ~ 0) over the window (z = -3).
M = translation_matrix([0, -2.9, -3]) @ rotation_matrix(-np.pi/2, [1, 0, 0])
```

Both `oled.stl` (blue) and `oled_screen.stl` (near-black) are transformed, colour-tagged, and added
as named nodes.

```bash
python3 cad/merge_oled_glb.py [in.glb=pcb/build/3d/flexisette.glb] \
                              [out=pcb/build/3d/flexisette_oled.glb]
```

| | Path |
|---|---|
| Input GLB (from `tsci export -f glb`) | `pcb/build/3d/flexisette.glb` |
| Output (OLED merged in) | `pcb/build/3d/flexisette_oled.glb` |

> **Not wired into a Make target.** `make fit` does not regenerate the GLB or run this merge, and
> `make show` only *points at* `flexisette_oled.glb`. The GLB path is manual: run
> `cd pcb && tsci export index.circuit.tsx -f glb -o build/3d/flexisette.glb`, then
> `python3 cad/merge_oled_glb.py`. Because nothing in the fit loop rebuilds it, **the GLB can go
> stale relative to the routed board** — regenerate it before sharing.

---

## The Blender beauty render — `render/render_assembly.py`

The Cycles hero shot of the full assembly: the real `pcb.stl` + `frame` + `panel` + `insert` +
OLED, in a studio with soft lights, floor, AgX tone-mapping and depth-of-field.

| Aspect | Setting |
|---|---|
| Engine / device | Cycles, **GPU `OPTIX`** (requires a GPU box — **not the dev machine**) |
| Samples / denoise | `samples = 220`, denoising on |
| Resolution | 1792 × 1120 |
| View transform | AgX, "Medium High Contrast", exposure −0.6 |
| Scale | `S = 0.001` (STL mm → Blender m) |
| Stack centring | `ZC = −0.0045` (centres the 9 mm stack about `z = 0`) |
| Explode | `EXPL = 0.0016` m — small, so layers read; **set `EXPL = 0` for a closed view** |
| Outputs | `render/out/flexisette_assembly.png` + a sibling `.blend` |

Z placement mirrors `render_fit.py` (in metres, scaled, offset by `ZC`):

| Part | `place(...)` Z | Explode |
|---|---|---|
| `pcb.stl` (falls back to `panel.stl` as a stand-in if absent) | 0.0 | −EXPL |
| OLED (`oled.stl` + `oled_screen.stl`) | `(0, 3 mm, −4 mm + ZC − EXPL)` — window, behind board, screen up | — |
| `frame.stl` | 1.57 | 0 |
| `panel.stl` | 7.43 | +EXPL |
| `insert.stl` | recentred, `rotate −90° X`, `(0, −0.0245, ZC + 0.0045)` | — |

Run it headless through the retry wrapper (Blender 5.0's bundled OpenColorIO has a ~15% flaky
segfault on this machine — each attempt is a fresh process, `LC_ALL=C` + retries clears it):

```bash
# from the repo root (top-level Makefile):
make assembly                       # render/out/flexisette_assembly.png
make blend-assembly                 # open the scene in the Blender GUI instead

# or directly via the wrapper:
BLENDER=/opt/blender-5.0.1-linux-x64/blender ATTEMPTS=5 \
  render/blender_render.sh render/render_assembly.py render/out/flexisette_assembly.png
```

The script saves the `.blend` first and only renders when `bpy.app.background` is true, so the GUI
path (`make blend-assembly`) builds the scene without auto-rendering — press F12 to render manually.

Sibling render scripts (`render/render_shell.py`, `render/render_frame.py`,
`render/render_spacers.py`) follow the same studio recipe for the printed parts in isolation; the
top-level `make frame|panel|insert|spacers|shell` targets drive them. Those do not consume the PCB —
only `render_assembly.py` and `render_fit.py` pull the routed board in.

---

## How to run and view — quick reference

| Goal | Command | Output |
|---|---|---|
| Full fit-check (both boards + OLED + 3 views) | `cd pcb && make fit` | `cad/build/fit_{iso,top,pop}.png` |
| Open the fit renders + print 3D paths | `cd pcb && make show` | opens `fit_top.png`, `fit_iso.png` |
| Just the bare board STL | `python3 cad/import_pcb.py ../pcb/index.circuit.kicad_pcb` | `cad/build/pcb.stl` |
| Just the populated board STL | `python3 cad/import_pcb.py ../pcb/index.circuit.tsx` | `cad/build/pcb_pop.stl` |
| Re-model the OLED | `python3 cad/oled.py` | `cad/build/oled*.stl` |
| Re-render the fit views | `python3 cad/render_fit.py [explode]` | `cad/build/fit_*.png` |
| Merge OLED into the GLB | `python3 cad/merge_oled_glb.py` | `pcb/build/3d/flexisette_oled.glb` |
| Blender beauty render (GPU box) | `make assembly` (repo root) | `render/out/flexisette_assembly.png` |
| Interactive 3D in the browser | `cd pcb && tsci dev` → 3D tab | live, `https://localhost:3020` |
| Open a GLB in a viewer | drag `flexisette_oled.glb` into <https://gltf-viewer.donmccurdy.com> | — |

`make show` prints, verbatim, where everything lives:

```
renders : cad/build/fit_{top,iso,pop}.png   (image viewer)
3D GLB  : pcb/build/3d/flexisette_oled.glb   (drag into https://gltf-viewer.donmccurdy.com, or Blender / OS 3D viewer)
STLs    : cad/build/*.stl    |    live 3D: cd pcb && tsci dev  (localhost:3020, 3D tab)
```

---

## Outputs all live in gitignored `build/` dirs

`.gitignore` excludes `**/build/`, so **none of these artifacts are committed** — they are real
files, regenerated on demand:

- `cad/build/` — `pcb.stl`, `pcb_pop.stl`, `oled.stl`, `oled_screen.stl`, `frame.stl`, `panel.stl`,
  `insert.stl`, the generated `_fit_*.scad`, and the `fit_*.png` renders.
- `pcb/build/3d/` — `flexisette.glb` (tscircuit), `flexisette_oled.glb` (merged), `flexisette.step`.
- `render/out/` — the Blender PNGs + `.blend` files (this dir is **not** under a `build/`, so its
  contents are not gitignored by the `build/` rule — they live under `render/out/`).

Always **re-export the board each pass** — a stale `pcb.stl` silently hides a moved connector. The
fit loop (`make fit`) regenerates the STLs and PNGs together; the GLB does not (see the merge note).

---

## Drift / staleness caveats found while documenting

- **Outline overhang is live, not reconciled.** The routed Edge.Cuts bbox is **102.24 × 63.76 mm**;
  `machine_params.SHELL_W = 100.5`, so the board overhangs the shell by **~1.7 mm in X** and
  `import_pcb.py` prints `dX=+1.7mm overhang` every run. Fix the outline or the param.
- **The GLB pipeline is out of the loop.** `make fit` never rebuilds `flexisette.glb` /
  `flexisette_oled.glb`; `make show` only opens them. Regenerate manually (`tsci export -f glb` +
  `merge_oled_glb.py`) or the shared GLB drifts from the current board.
- **Co-registration is dynamic, not anchored to holes.** `import_pcb.py` centres on the live bbox
  centre + Y-mirror — correct *only while board outline == shell outline*. The skill's preferred
  datum is the 4 corner mounting holes; this project uses the quicker bbox path, which the 1.7 mm
  overhang above will bias by ~0.85 mm until reconciled.
- **`render_assembly.py` needs a GPU box.** It hard-selects `OPTIX`; on a CPU-only dev machine the
  device setup yields no usable device. Use the OpenSCAD fit views for day-to-day work and reserve
  the Blender render for the GPU host. It also renders slightly exploded (`EXPL = 0.0016`) — set
  `EXPL = 0` for a closed product shot.
- **Insert orientation in `render_fit.py` is cosmetic.** A wrong rotate sign there flips the insert
  through the board but does not invalidate the board↔opening alignment read; the Blender assembly is
  where the insert pose is dialed in.

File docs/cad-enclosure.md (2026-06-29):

# CAD: the 3D-printed cassette shell

This document covers the parametric CAD of flexisette's physical enclosure — the 3D-printed
cassette shell that the flex PCB lives inside. Everything here is build123d (Python) plus a couple
of `trimesh` / `shapely` helpers for pulling geometry off the vendor STLs, all under
[`cad/`](../cad/). If you need to change a dimension, change it in **one** file
([`cad/machine_params.py`](../cad/machine_params.py)) and rebuild — that is the whole design
philosophy.

---

## 1. Concept: the cassette is a sandwich

A real Compact Cassette is a flat box about **100.5 × 64 × ~9 mm**. flexisette reproduces that box
as a **three-layer sandwich** stacked along Z (the thin axis):

```
  +Z  ┌──────────────────────────┐  ← top half      (PCB or printed panel)   PCB_T   = 1.57 mm
      │                          │
      │     spacer / frame       │  ← middle         (printed, sets the gap)  SPACER_GAP = 5.86 mm
      │                          │
  0   └──────────────────────────┘  ← bottom half    (the real flex PCB)      PCB_T   = 1.57 mm
                                                                              ─────────────────────
                                                                     CASSETTE_T = 9.00 mm total
```

* The **bottom half is the real PCB** — the cassette-shaped flex board (ESP32-S3 + OLED + audio).
* The **middle is a printed spacer/frame** that sets the inter-board gap and carries the head
  features and the screw bosses.
* The **top half** is either a second PCB or a 3D-printed face **panel** (`panel.py`) that stands in
  for a PCB so the stack still totals a standard cassette thickness.

The board outline, the tape window, the two reel windows, and the four corner screw holes are
**shared geometry**: the same cassette-face silhouette drives both the printed parts (projected off
the vendor shell) and the PCB outline, so the shell's openings land exactly over the board's
cutouts. That alignment is the whole point of the enclosure and is verified by the fit-check
(§9).

### Two part families

There are deliberately **two families** of geometry in `cad/`, and it matters which one you are
touching:

| Family | Files | Outline source | Used by |
|---|---|---|---|
| **Idealized / parametric** | `pcb_half.py`, `spacer.py`, `machine.py` | `RectangleRounded(SHELL_W, SHELL_H, CORNER_R)` — a clean rounded rectangle | the mate-based `machine.py` stack + MuJoCo/quick checks |
| **Vendor-extracted / production** | `frame.py`, `panel.py`, `insert.py`, `head_frame.py` | the **true silhouette** projected from the vendor STL (`side-1-plain.stl` / `side-1-insert.stl`) — angled bottom, real screw bosses, head cutouts | `make`, the Blender renders, `freecad_export.py`, the fit-check |

The parametric family is the simple conceptual stack (great for assembly logic and mates). The
vendor-extracted family is what you actually print, because it inherits the real cassette outline
(the angled "trapezoidal" bottom band, the head-holes region, the molded screw posts) that a deck
expects.

---

## 2. Conventions

These follow the repo's two build123d skills:

* **build123d-part** — each part file exposes a `part()` that returns one **watertight, single-body**
  solid, and a `__main__` block that exports it and prints a self-check
  (`bbox / bodies / watertight`). `pcb_half.py`, `spacer.py`, `frame.py`, `panel.py`,
  `head_frame.py`, `oled.py` all follow this.
* **build123d-machine** — `machine.py` is the **assembly**: it places parts in the stack and prints
  a manifest. Parts expose **named mate points** (`MATES`) rather than magic positions, so the
  assembler snaps `pcb_top` onto the spacer's `pcb_top` mate instead of hard-coding a Z.
* **Stack/Z convention** (from `pcb_half.py`): *+Z points OUT along the joining direction; the part
  origin sits on the contact face.* `MATES["outer"] = Pos(0,0,0)` (cassette exterior),
  `MATES["inner"] = Pos(0,0,T)` (face that touches the spacer).
* **Front edge**: `FRONT_Y = -SHELL_H/2` is the **head-holes edge** (the bottom of the cassette where
  the tape head and capstans poke through). All head/capstan/window features are placed relative to
  `FRONT_Y`.

---

## 3. `machine_params.py` — the single source of truth

Every dimension is a **named constant, derived rather than hand-tuned**. The thickness stack is the
clearest example: you set the target cassette thickness `CASSETTE_T`, and the frame thickness
`SPACER_GAP` *follows* by subtracting the two PCB halves — change `CASSETTE_T` and the spacer, frame,
panel datums, and insert thickness all move together. No part file contains a bare number that
should have been a parameter.

```python
CASSETTE_T = 9.0                     # nominal shell thickness  <-- tune this
PCB_T      = 1.57                    # each PCB half (0.062" board)
SPACER_GAP = CASSETTE_T - 2 * PCB_T  # frame height, DERIVED (= 5.86 mm)
```

### Footprint

| Const | Value | Meaning |
|---|---|---|
| `SHELL_W` | 100.5 mm | cassette width (X) |
| `SHELL_H` | 64.0 mm | cassette height (Y) |
| `CORNER_R` | 4.0 mm | outline corner radius |

### Thickness stack (Z)

| Const | Value | Meaning |
|---|---|---|
| `PCB_T` | 1.57 mm | each PCB half (standard 0.062" board) |
| `PANEL_T` | `= PCB_T` | printed face panel — subs for a PCB on one side |
| `CASSETTE_T` | 9.0 mm | target total shell thickness (**tune this one knob**) |
| `SPACER_GAP` | `CASSETTE_T - 2*PCB_T` = 5.86 mm | frame thickness, derived |

### Spacer walls

| Const | Value | Meaning |
|---|---|---|
| `WALL` | 3.0 mm | head-variant perimeter wall |
| `DUMMY_WALL` | 5.0 mm | dummy-variant wall (beefier, prints mostly solid) |

### Magnetic-head bay (head variant only — placeholder dims, refine against a real head)

| Const | Value | Meaning |
|---|---|---|
| `HEAD_BAY_D` | 9.0 mm | depth of the head shelf behind the front window (+Y) |
| `HEAD_POCKET_W` | 16.0 mm | head pocket width (X) |
| `HEAD_POCKET_H` | 6.0 mm | head pocket height (Z) — *intended* `< SPACER_GAP` (see §10) |

### Head-access window / capstans (used by `head_frame.py`)

| Const | Value | Meaning |
|---|---|---|
| `HEAD_WIN_W` | 24.0 mm | head-access window width in the front wall (matches insert mouth) |
| `HEAD_WIN_H` | 6.0 mm | head-access window height — *intended* `<= SPACER_GAP` (see §10) |
| `CAPSTAN_D` | 2.6 mm | capstan / guide clearance hole diameter |
| `CAPSTAN_DX` | 19.0 mm | capstan holes at ±this X from centre |

### Corner screws & bosses

The corner-screw strategy is **M2 thread-forming, tapped straight into the plastic** — a
non-structural cap, no heat-set, no backing nut, no through hole. The top and bottom PCB each tap a
**blind pilot from their own face**, and the pilots are short enough that they never meet in the
middle. Corners are thickened into **bosses** so the pilot clears the wall.

| Const | Value | Meaning |
|---|---|---|
| `SCREW_CLEAR_D` | 2.4 mm | M2 clearance (drilled in the PCB halves) |
| `SCREW_PILOT_D` | 1.7 mm | M2 thread-forming pilot bore in the plastic |
| `SCREW_PILOT_DEPTH` | 2.5 mm | blind pilot depth per face (`< GAP/2` so the two don't meet) |
| `SCREW_BOSS_D` | 7.0 mm | corner boss diameter |
| `SCREW_HEATSET_D` | 3.2 mm | *legacy* — kept for `head_frame.py` / older spacer variant |
| `SCREW_INSET` | 5.0 mm | *legacy* — boss inset for the parametric `head_frame` variant |

### 2-piece print: thin frame + separate tape-head protrusion

An alternative where the head protrusion prints separately and the PCBs notch to clear it.

| Const | Value | Meaning |
|---|---|---|
| `PROTR_W` | 70.2 mm | tape-head protrusion width (= vendor insert width) |
| `PROTR_CLEAR` | 0.8 mm | clearance around the protrusion (frame slot + PCB notch) |
| `NOTCH_H` | 18.0 mm | PCB bottom-edge notch depth (clears the ~16 mm protrusion) |
| `REEL_D` | 11.0 mm | reel window diameter in the PCB |
| `REEL_DX` | 20.0 mm | reel windows at ±this X from centre |

### Head-holes insert (measured from `side-1-insert.stl`)

| Const | Value | Meaning |
|---|---|---|
| `INSERT_W` | 70.2 mm | width along cassette X |
| `INSERT_H` | 16.0 mm | height along cassette Y (the front band) |
| `INSERT_T` | `= SPACER_GAP` | thickness, meant to equal the inter-PCB gap |
| `FRONT_Y` | `-SHELL_H/2` | the head-holes edge (front of the cassette) |

`machine_params.py` also re-exports `Location, Pos, Rot` from build123d and defines a small
`place(solid, frm, onto)` helper that snaps a part so its local mate `frm` lands on a world target
`onto` (`(onto * frm.inverse()) * solid`).

---

## 4. Part catalog

| Part | File | Family | What it is | Thickness | Outline source |
|---|---|---|---|---|---|
| **PCB half** | `pcb_half.py` | parametric | plain cassette-outline plate, used as top **and** bottom of the sandwich | `PCB_T` | `RectangleRounded` |
| **Spacer (head/dummy)** | `spacer.py` | parametric | the middle frame that sets the gap; `head` adds the head bay + insert slot | `SPACER_GAP` | `RectangleRounded` |
| **Frame** | `frame.py` | vendor-extracted | production spacer frame with the *real* outline + corner bosses + blind screw pilots | `SPACER_GAP` | `side-1-plain.stl` silhouette |
| **Panel** | `panel.py` | vendor-extracted | printed face that subs for the top PCB; carries reel holes + tape window + screw holes | `PANEL_T` | `side-1-plain.stl` silhouette |
| **Insert** | `insert.py` | vendor-extracted | the trapezoidal tape-head bridge at the cassette's front edge | ~8.8 mm (mesh) | fused `side-1/2-insert.stl` |
| **Head frame** | `head_frame.py` | vendor-extracted (legacy) | monolithic head-holes frame with heat-set bosses (older approach) | `SPACER_GAP` | `RectangleRounded` + parametric head |
| **OLED prop** | `oled.py` | render/fit prop | a modeled 0.96" SSD1306 module (no CDN 3D model exists) for the fit-check | — | hand-dimensioned |

### 4.1 `pcb_half.py`

The simplest part: `RectangleRounded(SHELL_W, SHELL_H, CORNER_R)` extruded `PCB_T`. It is the stand-in
for an actual PCB in the parametric stack, used for **both** the top and bottom of the sandwich. It
defines the canonical mate convention (`MATES = {"outer": Pos(0,0,0), "inner": Pos(0,0,T)}`) that the
rest of the assembly snaps against.

### 4.2 `spacer.py` — the parametric middle, two variants

`part(variant)` extrudes a rounded-rectangle perimeter frame of height `SPACER_GAP`, wall thickness
chosen by variant:

* **`variant="dummy"`** — beefier closed frame (`DUMMY_WALL = 5.0`), no openings. The plain
  structural body; prints mostly-solid with slicer infill. Use it when you don't need real deck
  playback.
* **`variant="head"`** (default) — `WALL = 3.0`, plus three head features cut/fused at the front
  (`FRONT_Y`) edge:
  1. a **front slot** (`Box(INSERT_W, WALL*2.5, GAP+0.2)`, subtract) to receive the head-holes
     insert;
  2. a **head-bay shelf**: a cross-bar spanning the inner width that fuses to both side walls, set
     `WALL + HEAD_BAY_D/2` behind the front (the `bay_y` datum);
  3. a **head pocket** cut into that bar (`HEAD_POCKET_W × HEAD_POCKET_H`) so a harvested magnetic
     transmit head can seat behind the window and play in a real deck.

`MATES(variant)` returns `pcb_bottom` (`Pos(0,0,0)`), `pcb_top` (`Pos(0,0,GAP)`), and — for the head
variant — `insert_seat` and `head_seat` mate points at the front edge.

### 4.3 `frame.py` — production spacer (the one you print)

This is the vendor-extracted counterpart of the head spacer. `_extract()` does the geometry lift:

1. `trimesh.load(side-1-plain.stl)` and `.projected(normal=[0,1,0])` to get the **face-on silhouette**
   (the true cassette outline, including the angled bottom and the protrusion cutout).
2. take the largest polygon, recentre it on its bbox centre, and remap projection coords
   `(a0=height, a1=width)` into frame coords `(x=width, y=height)`.
3. find the **four corner screw centroids** from the small interior rings (`area < 15`).
4. build the **cavity** as the outline inset by `WALL` (mitre join), then **subtract a `BOSS_D`-wide
   disc at each screw** so the corners stay solid — those discs become the screw bosses.

`part()` extrudes `outline − cavity` to `SPACER_GAP`, then drills **blind thread-forming pilots from
both faces** (`Cylinder(PILOT_D/2, PILOT_DEPTH*2)` at `z=GAP` and at `z=0`). `SIMP = 0.4 mm` is the
outline simplification tolerance.

### 4.4 `panel.py` — printed face panel

Same `side-1-plain.stl` silhouette as the frame, but it keeps **all** the interior rings as holes:
the two reel windows, the central tape window, and the four corner screw holes (`_rings()` returns
`ext` plus every interior). `part()` subtracts those from the face and extrudes `PANEL_T` (= `PCB_T`,
so panel + frame + PCB still equals 9 mm). It caps the frame on one face while a PCB goes on the
other; the intent is to print the cassette art as a multicolor first layer like the vendor model.

### 4.5 `insert.py` — the tape-head bridge

The vendor split the front trapezoidal head piece into two color-halves for multicolor first-layer
printing (`side-1-insert.stl` + `side-2-insert.stl`). `solid()`:

1. loads both halves, recentres each on its bounding-box centroid;
2. rotates `side-2` **180° about Z** (the vendor halves mate open-face-to-open-face, one flipped);
3. `trimesh.boolean.union(..., engine="manifold")` into one closed trapezoidal shell.

It prints solid (slicer infill). The trapezoidal footprint clears the PCB/frame cutouts and seats
into the frame's trapezoidal bottom section. This is the literal mesh; the **parametric**, editable
version of the same shape is reconstructed in `freecad_export.py` (§7) by projecting the front
silhouette and padding it.

### 4.6 `head_frame.py` — legacy monolithic head frame

An **older, all-parametric** alternative to `frame.py` (note: it does *not* use the vendor outline —
it builds from `RectangleRounded`). One watertight body: a perimeter frame at `SPACER_GAP`, four
corner bosses at `±(W/2 - SCREW_INSET, H/2 - SCREW_INSET)` fused in, a parametric head-access window
in the front wall (`HEAD_WIN_W × HEAD_WIN_H`), two capstan clearance holes (axis along Y), and **M2
heat-set bores** through the bosses (`SCREW_HEATSET_D`). It is kept for reference but superseded by
the `frame.py` blind-pilot approach (no heat-set inserts). If you are choosing one, use `frame.py`.

### 4.7 `oled.py` — display fit prop

Not a printed part — it models the 0.96" SSD1306 module (blue PCB + dark glass + 4-pin header)
because tscircuit has no CDN 3D model for it. It exports `oled.stl` (module, blue) and
`oled_screen.stl` (glass + lit area, near-black) so the fit-check can colour the screen separately.
Origin: module centred in XY, back at `z=0`, **screen on +Z**, so it mounts on the back of the board
with the screen facing out through the tape window. Module body is `27×27×1.2`, glass `25.5×16.5`,
active area `21.7×10.9` (the 128×64 lit rectangle).

---

## 5. Screws, bosses, head bay — strategy notes

* **Why blind thread-forming pilots (current, `frame.py`):** an M2 screw self-taps into a `1.7 mm`
  pilot in PLA. Each PCB half drills an M2 clearance hole (`SCREW_CLEAR_D = 2.4`) and screws into the
  frame from its own side; the two pilots (`SCREW_PILOT_DEPTH = 2.5` each) stay short of meeting in a
  `5.86 mm` gap. No heat-set inserts, no nuts, no through holes. The corner is thickened to
  `SCREW_BOSS_D = 7.0` so the pilot has wall around it — `frame.py` carves the cavity *around* a boss
  disc at each screw so the corners stay solid.
* **Why this matters for the board:** the PCB's four corner clearance holes must sit on the same
  centres `_extract()` pulls from the vendor shell. Those centres are shared geometry; if you move a
  screw on the board, move it in the shell outline too (or vice versa).
* **Head bay (head spacer only):** the cross-bar shelf fuses to both side walls for rigidity and
  gives the magnetic head a pocket to seat in, set just behind the front window so the head face
  lines up with the head-access opening. These dims (`HEAD_BAY_D`, `HEAD_POCKET_*`) are placeholders
  to be refined against a real harvested head.

---

## 6. Assembly: `machine.py`

`machine.py` builds the conceptual sandwich from the **parametric** family (`pcb_half` + `spacer`):

```python
def assembly(spacer_variant="head"):
    return [
        ("pcb_bottom", Pos(0, 0, 0)                    * pcb_half.part()),
        ("spacer",     Pos(0, 0, M.PCB_T)              * spacer.part(spacer_variant)),
        ("pcb_top",    Pos(0, 0, M.PCB_T + M.SPACER_GAP) * pcb_half.part()),
    ]
```

The Z datums are **param-derived** (the layout owns them — bottom at 0, spacer at `PCB_T`, top at
`PCB_T + SPACER_GAP`). Running it:

* exports a **raw spacer at the origin** (`spacer_<variant>.stl`) for clean single-part renders /
  printing;
* exports each **positioned** assembly part (`pcb_bottom.stl`, `spacer.stl`, `pcb_top.stl`; the
  `head` variant keeps the default unsuffixed names so the render scripts find them, `dummy` gets a
  `_dummy` suffix);
* prints a **MANIFEST** of each part's bbox and Z range, plus the `TOTAL`;
* exports a **combined STEP** (`flexisette_shell_<variant>.step`) via a build123d `Compound`.

Example manifest (head variant): `pcb_bottom`, `spacer`, `pcb_top` each `100.5 × 64.0` in XY, total
Z range `[0, 9.0]`.

---

## 7. Building

All build123d scripts are run from inside `cad/` (they `import machine_params` by sibling path and
write to `cad/build/`).

### Per-part

```bash
cd cad
python3 pcb_half.py        # prints a validity / bbox self-check (no file export)
python3 spacer.py          # prints bbox for both dummy + head variants
python3 frame.py           # -> build/frame.stl + build/frame.step
python3 panel.py           # -> build/panel.stl + build/panel.step
python3 insert.py          # -> build/insert.stl
python3 head_frame.py      # -> build/head_frame.stl + build/head_frame.step  (legacy)
python3 oled.py            # -> build/oled.stl + build/oled_screen.stl
```

### Assembly

```bash
cd cad
python3 machine.py          # default = head
python3 machine.py head     # spacer with head bay + insert slot
python3 machine.py dummy    # plain structural spacer
# -> build/{pcb_bottom,spacer,pcb_top}.stl + build/flexisette_shell_head.step (+ spacer_head.stl)
```

### Editable FreeCAD trees

```bash
cd cad && python3 freecad_export.py     # -> build/{frame,panel,insert}.FCStd
```

`freecad_export.py` re-expresses `frame`, `panel`, and `insert` as `featuretree` IR (reusing the
*same* extracted geometry the build123d scripts use) and emits `.FCStd` files that open in FreeCAD
with their operations in the left-panel tree — sketch → pad → pockets, instead of a frozen STEP
lump. Notably it reconstructs the insert **parametrically**: it projects the fused vendor mesh's
front silhouette (trapezoid + head/capstan openings) and pads it, giving an editable solid insert in
one step. Requires the FreeCAD AppImage (see the `featuretree` skill).

### Makefile (parts + Blender renders)

The top-level [`Makefile`](../Makefile) wraps the production family and the renders:

| Target | Does |
|---|---|
| `make` / `make parts` | build + render frame, panel, insert, and the stacked assembly |
| `make cad` | build123d → STL/STEP for frame, panel, insert |
| `make frame` / `panel` / `insert` / `assembly` | one render |
| `make verify` | re-run `frame.py`, `panel.py`, `insert.py` watertight/validity self-checks |
| `make freecad` | the `.FCStd` feature trees |
| `make clean` | remove generated STL/STEP/FCStd/PNG |

Note `make cad` only builds the vendor-extracted parts (`frame`, `panel`, `insert`); the parametric
`spacer`/`pcb_half` stack and the `machine.py` assembly are run directly with `python3`.

### Outputs

Everything lands in **`cad/build/`**: per-part `*.stl` / `*.step`, the combined
`flexisette_shell_<variant>.step`, the `*.FCStd` editable trees, the OLED props, and the fit-check
`fit_*.png` / `_fit_*.scad` (§9). Blender PNGs go to `render/out/`.

---

## 8. Vendor sources

The production parts are derived from two purchased/remixed cassette models (full provenance in
[`assets/DOWNLOADS.md`](../assets/DOWNLOADS.md)):

* **`assets/cassette-shell-minecraft/`** — *Minecraft Soundtrack Cassette Shell remix*
  (Printables #836410). This is the one the CAD reads:
  * `side-1-plain.stl` — plain shell half, the **silhouette source** for `frame.py` and `panel.py`.
  * `side-1-insert.stl` / `side-2-insert.stl` — the front **head-holes bridge** (tape-head window,
    capstan holes, pinch-roller openings, registration tabs), `70.15 × 8.8 × 16.0 mm`. This is the
    "third part" `insert.py` fuses, and the dimensional reference behind `INSERT_W/H/T`.
* **`assets/cassette-shell/`** — *Cassette Shell Sides A+B* (Printables #176745). A reference
  full-shell model (side_a measured `102.25 × 8.8 × 63.75 mm`) with no separate head-holes part —
  kept for comparison, not currently read by the CAD.

> Licenses/authors for both are **TBD** until confirmed on the Printables pages (the assistant can't
> auto-fetch those pages — see the warning in `DOWNLOADS.md`). Verify before any redistribution.

---

## 9. How the shell connects to the PCB

The enclosure only "works" if its openings line up with the board, so the shell and the board are
co-designed against a **shared cassette-face profile** and checked in 3D. Two scripts bridge the
`pcb/` and `cad/` subsystems (this is the `pcb-enclosure-fit` workflow; see also
[`docs/3d-fit-and-renders.md`](./3d-fit-and-renders.md)):

* **`cad/import_pcb.py`** brings the board in as an STL, dispatching on extension:
  * `*.kicad_pcb` → `kicad-cli ... export step` → the **routed but bare** board (tscircuit
    footprints carry no KiCad 3D models). It is **Y-mirrored** (KiCad is Y-down; the CAD is Y-up),
    centred in XY, and lowest point set to `z=0` → `build/pcb.stl`. Best for layer registration. It
    also prints an `outline vs shell` check (`dX` overhang against `SHELL_W × SHELL_H`).
  * `*.tsx` → `tsci export -f step` → the **populated** board (component bodies from EasyEDA CDN
    models) → `build/pcb_pop.stl`. Best for connector / display-protrusion clearance.
* **`cad/render_fit.py`** stacks the real board with the printed parts at the **same
  `machine_params` Z datums** as `machine.py` (`pcb` at 0, `frame` at `PCB_T`, `panel` at
  `PCB_T + SPACER_GAP`), drops the `oled` prop behind the board at the window, and seats the
  `insert` at `FRONT_Y`, then renders three OpenSCAD views:
  * `build/fit_iso.png` — exploded iso (board cutouts vs frame read apart);
  * `build/fit_top.png` — straight top-down **window / reels / screws alignment** check;
  * `build/fit_pop.png` — the populated board ghosted under the frame (connector clearance).

The placement-time loop is:

```bash
py/bin/python cad/import_pcb.py ../pcb/index.circuit.kicad_pcb   # bare, routed -> pcb.stl
py/bin/python cad/render_fit.py                                  # iso + top + pop fit images
```

Treat connector/cutout/screw alignment as a **placement gate**: the shell's window, reels, and screw
bosses are constraints on where parts go on the board. If the top-down image shows the OLED off its
window or a screw off its boss, the fix is to move it on the board (or adjust the shared outline) —
not to nudge the shell independently.

---

## 10. Known discrepancies / gotchas

These are real mismatches found while documenting; flag for whoever next edits the params:

1. **Stale "~12 mm / 8.8 mm" comments vs `CASSETTE_T = 9.0`.** The `machine_params.py` module
   docstring says *"total thickness = a standard cassette (~12 mm)"* and the `INSERT_T = SPACER_GAP`
   comment says *"8.8 mm thickness == the inter-PCB gap"* — both describe an **earlier** target where
   `CASSETTE_T ≈ 12` (→ `SPACER_GAP ≈ 8.86 ≈` the vendor's 8.8 mm insert). With the current
   `CASSETTE_T = 9.0`, **`SPACER_GAP` is actually 5.86 mm**, so `INSERT_T = 5.86 mm`, *not* 8.8 mm.
   The vendor insert mesh is still ~8.8 mm thick, so `insert.py`'s physical part is thicker than the
   gap the frame provides — reconcile `CASSETTE_T`/`INSERT_T` against the real insert before relying
   on it.
2. **Head features exceed the gap.** `HEAD_POCKET_H = 6.0` and `HEAD_WIN_H = 6.0` are both commented
   *"must be `< / <= SPACER_GAP`"*, but `SPACER_GAP = 5.86 mm`, so both are **slightly too tall** for
   the current 9 mm stack. `spacer.py`'s head pocket / `head_frame.py`'s window will punch the full
   height (effectively breaking through). Either trim these to `≤ 5.8` or bump `CASSETTE_T`.
3. **Two outline sources can drift.** The parametric family uses `RectangleRounded(SHELL_W, SHELL_H)`
   while the production family uses the projected vendor silhouette (which measures ~102 mm wide, not
   100.5). `import_pcb.py`'s own check expects the board to match `SHELL_W × SHELL_H = 100.5 × 64`.
   When validating fit, prefer the vendor-extracted parts (`frame`/`panel`) — they carry the real
   outline and screw centres.
4. **`INSERT_W = 70.2` vs measured `70.15`** and **`PROTR_W = 70.2`** — rounded; harmless but note the
   `DOWNLOADS.md` measurement is `70.15`.
5. **`head_frame.py` is legacy** (heat-set bosses, non-vendor outline) and is superseded by
   `frame.py` (blind thread-forming pilots, real outline). `SCREW_HEATSET_D` / `SCREW_INSET` exist
   only for it.

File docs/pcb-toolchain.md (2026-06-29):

# PCB toolchain — design, generation, and routing

This document covers how the **flexisette** PCB is described in code, generated, and
routed: the tscircuit (React/TSX) source, the modular-subcircuit architecture, and the
`route.sh` place → route → inject pipeline that lands a fully-routed `*.kicad_pcb`.

It is scoped to *getting a routed board*. It deliberately does **not** cover:

- the round-trip floorplan loop (`make place` / `make sync`) or the auto-orient pass
  (`make untangle`) — see `docs/placement.md`.
- Gerbers / drill / BOM / CPL export — see `docs/fabrication.md` (`make fab`).

Everything lives under `pcb/`. Paths below are relative to that directory unless noted.

---

## 1. Modular-subcircuit architecture

### Why monoliths choke tscircuit

tscircuit's `sequential-trace` autorouter routes the *whole* board as one problem. A
single flat board with the ESP32-S3 (49 pads), USB-C, charger, amp, and OLED all in one
net graph blows up the router's search: it stalls, spins past the per-block timeout, and
leaves nets unrouted. The fix is to **route each functional block in isolation** and only
bridge the handful of buses that cross blocks.

### The four blocks

Each functional block is a `<subcircuit>` with **its own `autorouter="sequential-trace"`**
and its own GND pour. A subcircuit routes as a self-contained board, so the router only
ever sees one block's worth of nets at a time.

| Block | Component / file | Exports |
|---|---|---|
| `McuBlock` | `modules/mcu.circuit.tsx` | `McuBlock`, default `<board>` wrapper |
| `PowerBlock` | `modules/power.circuit.tsx` | `PowerBlock`, default `<board>` wrapper |
| `AudioBlock` | `modules/audio.circuit.tsx` | `AudioBlock`, default `<board>` wrapper |
| `DisplayBlock` | `modules/display.circuit.tsx` | `DisplayBlock`, default `<board>` wrapper |

Each module file exports **two** things: the named block component (composed into the
real board) and a default `() => <board>…</board>` wrapper so the block can be built and
route-checked *standalone* (`make modules`, `make routecheck`). The standalone wrapper
gives each block a small dummy board size (e.g. `40mm × 40mm` for mcu).

Every block takes `name`, `pcbX`, `pcbY` props so the top level can position it, and
spreads `{...JLCPCB}` (see §6) onto its `<subcircuit>` — the board-level fab prop does
**not** reach traces/vias drawn *inside* a subcircuit, because each subcircuit autoroutes
independently.

### Buses cross blocks via *named nets*

Inside a block, signals that leave the block are wired only to a **named net**
(`net.SDA`, `net.BCK`, `net.V3V3`, …) on the chip pin — not to the other block. For
example, in `mcu.circuit.tsx`:

```tsx
<trace from="U1.IO8" to="net.SDA" />  <trace from="U1.IO9" to="net.SCL" />
<trace from="U1.IO5" to="net.BCK" />  <trace from="U1.IO6" to="net.WS" />
```

tscircuit **scopes `net.X` per subcircuit**, so `net.SDA` in the mcu block and `net.SDA`
in the display block are *not* automatically the same node. The top-level board
(`index.circuit.tsx`) makes the cross-block link explicit by bridging each end to the
*board-level* net:

```tsx
<trace from=".mcu .U1 .IO8" to="net.SDA" /><trace from=".display .OLED .SDA" to="net.SDA" />
```

Power and ground are bridged the same way, each via one known cap/connector pin per block:

```tsx
<trace from=".power .C_OUT .pin1" to="net.V3V3" /><trace from=".power .C_OUT .pin2" to="net.GND" />
<trace from=".mcu .C_BULK .pin1" to="net.V3V3" /><trace from=".mcu .C_BULK .pin2" to="net.GND" />
<trace from=".audio .C3 .pin1" to="net.V3V3" /><trace from=".audio .C3 .pin2" to="net.GND" />
<trace from=".display .OLED .VCC" to="net.V3V3" /><trace from=".display .OLED .GND" to="net.GND" />
```

The consequence: after export, each of these shared signals appears under **several net
codes that all reduce to the same name** (one per subcircuit scope plus the bridge). KiCad
treats those as false shorts. `merge_nets.py` (§4, §5) reconciles them back into one flat
netlist *before* routing — recovering the clean netlist you would have had if the board
were a non-modular monolith, without paying the monolith's routing cost.

---

## 2. The board

`index.circuit.tsx` composes the four blocks onto the real cassette face:

```tsx
<board outline={outline} layers={2} autorouter="sequential-trace" {...JLCPCB}>
```

### Floorplan

Blocks are placed by signal flow, keeping the tape window and reels clear:

| Block | `pcbX, pcbY` | Rationale |
|---|---|---|
| `McuBlock` "mcu" | `-38, 2` | left end, pulled in to clear the left reel |
| `PowerBlock` "power" | `2, 20` | top band |
| `AudioBlock` "audio" | `24, -9` | right end, in the narrow column |
| `DisplayBlock` "display" | `-2, -12` | strip just below the tape window |

### Parts table

**MCU — `modules/mcu.circuit.tsx`** (pin map in the file header: I2C `SDA=IO8 SCL=IO9` |
I2S `BCK=IO5 WS=IO6 DIN=IO7` | amp `SD=IO4` | buttons `BTN_A=IO10 BTN_B=IO11` |
`boot=IO0 reset=EN`). Native USB on `IO19=D-`, `IO20=D+` — there is **no** USB-UART
bridge; the ROM enumerates as USB-CDC for flashing and audio upload.

| Ref | Part | JLC | Notes |
|---|---|---|---|
| `U1` | ESP32-S3-WROOM-1-N16R8 | C2913202 | 16 MB flash / 8 MB PSRAM; pins 41–49 are the EPAD, all tied to GND |
| `C1` | 100 nF (0402) | — | bottom-side decap, placed by `Decap` helper on the `3V3` pin |
| `R_EN` / `C_EN` | 10 k / 100 nF | — | EN reset pull-up + cap |
| `R_BOOT` | 10 k | — | IO0 boot pull-up (no boot/reset *buttons* — USB-CDC esptool resets over USB) |
| `C_BULK` | 22 µF (0805) | — | 3V3 bulk; `pin1/pin2` are the V3V3/GND bridge to the board |
| `SW_A` / `SW_B` | TS_1187A_B_A_B tactile | C318884 | user buttons (play/pause, next) |

**Power — `modules/power.circuit.tsx`** (USB-C 5 V → TP4056 LiPo charger → AO3401 load-share
→ ME6211 LDO 3V3; VSYS = USB through Schottky D1 when plugged, else battery through P-FET Q1):

| Ref | Part | JLC | Notes |
|---|---|---|---|
| `USBC` | TYPE-C-31-M-12 receptacle | C165948 | VBUS/GND/shield, CC, D+/D- (both orientations tied) |
| `R_CC1` / `R_CC2` | 5.1 k (0402) | — | CC1/CC2 pulldowns (advertise UFP) |
| `U_CHG` | TP4056 (ESOP8) | C16581 | charger; EPAD + `GV_CHG` via stitch GND to bottom pour |
| `R_PROG` | 2 k | — | charge-current program |
| `C_BAT` | 10 µF (0805) | — | battery cap |
| `J_BAT` | S2B-PH JST 2-pin | C295747 | LiPo connector (VBAT/GND) |
| `D1` | B5819W_SL Schottky | C8598 | USB → VSYS |
| `Q1` | AO3401A P-FET | C347476 | BAT → VSYS when USB off; body diode oriented so it can't back-charge |
| `R_G` | 100 k | — | Q1 gate |
| `U_LDO` | ME6211C33M5G | C82942 | LDO 3V3 out |
| `C_IN` / `C_OUT` / `C5` | 1 µF / 1 µF / 22 µF | — | LDO in/out + bulk |

**Audio — `modules/audio.circuit.tsx`** (MAX98357A I2S class-D amp straight into a speaker,
no DAC; mono via `SD_MODE` biased > 1.4 V = Left; powered from V3V3 ≈ 1 W/4 Ω):

| Ref | Part | JLC | Notes |
|---|---|---|---|
| `U2` | MAX98357AETE_T | C910544 | I2S amp; EPAD to GND; GAIN_SLOT left floating = 9 dB |
| `C3` | 10 µF (0805) | — | VDD bulk; `pin1/pin2` are the V3V3/GND bridge |
| `C2` | 100 nF (0402) | — | VDD bypass |
| `R3` | 100 k | — | SD_MODE pulldown (amp off at boot) |
| `J_SPK` | S2B-PH JST 2-pin | C295747 | speaker out (OUTP/OUTN) |

**Display — `modules/display.circuit.tsx`** (0.96" SSD1306 OLED on I2C, mounted on the
**back** so it glows through the tape-window cutout):

| Ref | Part | Notes |
|---|---|---|
| `OLED` | SSD1306 0.96" module | placed as a 4-pin `<chip>` on `layer="bottom"` with a hand-written footprint: 4 plated holes (`GND/VCC/SCL/SDA`) + a 27×27 mm silkscreen body over the window |
| `R1` / `R2` | 4.7 k (0402) | I2C pull-ups on SDA/SCL |

### Nets

| Net | Role | Crosses blocks? |
|---|---|---|
| `V3V3`, `GND` | power rails | yes — bridged from every block (GND also gets a bottom pour) |
| `USB_DP`, `USB_DM` | native USB D+/D- | power (USB-C) ↔ mcu |
| `SDA`, `SCL` | I2C | mcu ↔ display |
| `BCK`, `WS`, `DIN`, `SD` | I2S + amp shutdown | mcu ↔ audio |
| `VBUS`, `VBAT`, `VSYS` | power-internal | no — single net code, untouched by `merge_nets.py` |

### Outline and interior cutouts

The board outline is the **real cassette face**, a 36-point polygon in
`lib/cassette_outline.json`, spanning x ∈ [-51.125, 51.125] (≈ 102 mm) and
y ∈ [-31.875, 31.875] (≈ 64 mm), including the bottom-centre head-notch. It is passed
straight to `<board outline={outline}>`.

The interior holes come from `lib/cassette_holes.json` (`outer` + 7 `holes`), recovered
from the CAD source (`cad/panel._rings()`, cassette STL). `index.circuit.tsx` maps each
hole to a tscircuit `<cutout>` — which exports as an Edge.Cuts polygon — classifying by
bounding-box width:

| Hole class | Count | `<cutout>` | Width test |
|---|---|---|---|
| Tape window | 1 | `shape="rect"` (`WIN*`) | `w > 18` (≈ 21 × 12 mm; OLED glows through it) |
| Reel / drive holes | 2 | `shape="circle"` (`REEL*`) | `5 ≤ w ≤ 18` (≈ 11 mm, centred ±21, 3) |
| Corner screw holes | 4 | `shape="circle"` (`SCREW*`) | `w < 5` (≈ 2.5 mm) |

Each cutout is centred on its hole's bbox center (`pcbX/pcbY` = center, matching the rect
convention). These cutouts are **routing obstacles** the Freerouting step must avoid — see
`add_cutout_keepouts.py` (§4).

The GND copper pour is declared with `<copperpour connectsTo="net.GND" layer="bottom" />`,
but note this is **dropped by the kicad_pcb exporter** — the real pour is added later by
`add_plane.py` (§3, §4).

---

## 3. The place → route → inject pipeline

`scripts/route.sh` is the repeatable, placement-first pipeline. It exports the board,
reconciles nets, keeps out the holes, routes with Freerouting, then injects the result
into a live KiCad via the IPC API and triages DRC. It is run **directly** (there is no
`make route` target):

```bash
bash scripts/route.sh                  # full run, fast router cap
MP=100 OIT=20 bash scripts/route.sh    # (see caveat below — v2.1.0 ignores MP/OIT)
DISPLAY=:0 bash scripts/route.sh       # X display the relaunched pcbnew runs on
VARIANT=glow bash scripts/route.sh     # apply a non-default saved placement
```

Prerequisites: `tsci` (via bun), `freert` (Freerouting CLI at `~/.local/bin/freert`),
`kipy`, and a KiCad with `api.enable_server=true`.

### Steps, in order

| # | Action | Tool / command |
|---|---|---|
| 1 | Export placement to `index.circuit.kicad_pcb` | `tsci export -f kicad_pcb index.circuit.tsx -o index.circuit.kicad_pcb` |
| 2 | Apply the saved floorplan on top of the `.tsx` defaults | `apply_placement.py <VARIANT> index.circuit.kicad_pcb` (see `docs/placement.md`) |
| 3 | **Placement gate** — fail if any part is off-outline / in a hole | `outline-check.mjs index.circuit.tsx` |
| 4 | Reconcile fragmented cross-subcircuit nets | `merge_nets.py index.circuit.kicad_pcb --write` |
| 5 | Export the Specctra DSN | `tsci export -f specctra-dsn index.circuit.tsx -o build/index.dsn` |
| 6 | Keepout the interior holes in the DSN | `add_cutout_keepouts.py index.circuit.kicad_pcb build/index.dsn` |
| 7 | Route with Freerouting → `build/index.ses` | `freeroute.sh build/index.dsn` |
| 8 | (Re)launch pcbnew on the fresh board | `pkill` old pcbnew, `rm /tmp/kicad/api.sock`, `setsid pcbnew …`, wait for `kipy` |
| 9 | Add the GND pour (`<copperpour>` doesn't export) | `add_plane.py GND B.Cu --replace` |
| 10 | IPC-inject the SES tracks/vias into the live board | `apply_ses_ipc.py build/index.ses --save --clear` |
| 11 | DRC triage | `drc_check.py index.circuit.kicad_pcb` |

The **placement gate** (step 3) is load-bearing: tscircuit has no keep-in, so a part can
sit in the head-notch, off the edge, or on a reel/screw hole. Routing a bad floorplan only
hides the problem, so the gate exits non-zero and aborts (override with `FORCE=1`).

For a **4-layer** board, after step 8 add inner-plane zones and route signals only:

```bash
python3 scripts/add_plane.py GND  In1.Cu --replace
python3 scripts/add_plane.py V3V3 In2.Cu --replace --priority 1
```

> **Note on step numbering.** The `route.sh` echo labels are internally inconsistent
> (steps print `[1/8]`, `[2/8]`, then `[3/8]`, `[3/7]`, `[4/7]` … `[7/7]`, with `[3/…]`
> appearing twice). The *sequence* above is what actually runs; the printed `n/N` labels
> are cosmetic and stale.

### Standalone Freerouting (`make freeroute`)

`make freeroute` is the *measure/route a board on its own* path and is distinct from the
full `route.sh`. It calls `freeroute.sh` on the `.tsx` (which exports its own DSN), not on
the keepout-patched DSN, and stops at the SES:

```bash
make freeroute                  # FILE=index.circuit.tsx by default
make freeroute FILE=modules/mcu.circuit.tsx
```

---

## 4. KiCad-IPC reality

### Why IPC injection (the GUI rejects the SES)

The obvious path — KiCad GUI *File ▸ Import ▸ Specctra Session* — **rejects a SES routed
from tscircuit's DSN**: it chokes on the foreign component/padstack ids tscircuit emits.
`apply_ses_ipc.py` does what that GUI import does, but **headless against a running
pcbnew** through the IPC API, so the foreign ids never matter.

### The kipy API

`apply_ses_ipc.py` and `add_plane.py` both drive KiCad through `kipy`
(`import kipy; b = kipy.KiCad().get_board()`), which talks to pcbnew over a socket at
`/tmp/kicad/api.sock`. KiCad must be launched with `api.enable_server=true`. The board
object exposes `get_nets`, `get_footprints`, `get_pads`, `get_shapes`, `get_zones`,
`create_items`, `remove_items`, `refill_zones`, and `save`.

`apply_ses_ipc.py` is clean where the older SWIG injector (`apply_ses.py`, still in
`scripts/` as the deprecated path) was not, because **net assignment is authoritative,
not geometric** — so there are no V3V3/GND mislabel shorts:

| SES net name | Mapped to |
|---|---|
| `Net-(REF-PadN)` | the kipy net of pad `(REF, N)` (a `_source_component_<n>` infix is stripped) |
| `NAME_source_net_<n>` | the kipy net named `NAME` (GND / V3V3 / SCL / SDA / USB_*) |

The DSN→KiCad coordinate transform is fixed and verified exact on flexisette
(`resolution = (um 10)` ⇒ 10000 units/mm; board placed at +100, +100 mm; Specctra Y is up,
KiCad Y is down):

```
x_nm = u*100 + 100_000_000
y_nm = 100_000_000 - u*100
w_nm = w*100
```

`--save` writes the board (default is a dry-run report); `--clear` rips up existing
tracks/vias first for a clean re-route. After creating items it calls `refill_zones()` and
`save()`. Geometry is injected **verbatim** — an experiment that snapped endpoints to pad
centres added crossings/shorts without reducing unconnected, so the residual unconnected
tail is the genuine route tail, not off-pad slop.

### `add_plane.py` — the GND pour the exporter drops

`tsci export -f kicad_pcb` silently drops `<copperpour>` (the exported board has 0 zones),
so the ground pour is added back via IPC. `add_plane.py GND B.Cu --replace` builds a
rectangular zone from the board bbox; KiCad clips it to the real Edge.Cuts on fill, so the
pour follows the cassette outline and window cutout automatically. It warns if the filled
zone is not a single unbroken island (orphaned regions). Because GND lives on a real pour,
injected GND tracks are redundant copper — a missed GND stub can't orphan a pad.

### Freerouting v2.1.0 — the pin and its quirks

`freeroute.sh` pins **Freerouting v2.1.0** (the version that works for tscircuit DSNs):

- **`-mp` / `-oit` are ignored**, as is `router.max_passes` in `freerouting.json`. v2.1.0
  runs to its built-in default (9999 passes); you cannot cap passes. The only bound is the
  wall timeout `MAXT` (default 120 s). *(Caveat: the `route.sh` header's
  `MP=100 OIT=20 … final grind` example therefore has no effect — those vars are passed
  but ignored.)*
- It writes the `.ses` **only on convergence** (no improvement for a while). A routable
  board converges in seconds; a board it can't fully route (e.g. a keepout that strands a
  net) **oscillates forever and never writes** — so on a timeout you get a log but **no
  SES**. For *measuring* a placement, run a short `MAXT` and read the unrouted count from
  `build/freeroute.log`, not from the SES.
- It emits an empty `(host_version )` that KiCad's parser rejects; `freeroute.sh` patches
  it to `(host_version "freerouting")` with `sed`.
- **Do not upgrade to v2.2.x** for this flow: it needs Java 25 *and* its stricter DSN
  parser rejects the tscircuit DSN (`padstack name expected at 'V3V3'`).

---

## 5. Net reconciliation, DRC triage, and fab rules

### `merge_nets.py` — collapse fragmented nets by name

Because `net.X` is per-subcircuit (§1), a shared signal exports as several net codes that
all reduce to the same base name (SDA appears ~5×, V3V3 as ~9 codes). Routed, KiCad flags
these as false `shorting_items`. `merge_nets.py` collapses every signal to **one canonical
net by name**, *before* routing, giving the modular flow the same flat netlist a monolith
would have. It groups codes by a canonical base:

| Net-table name pattern | Canonical base |
|---|---|
| `<anything> to net.<X>` | `X` (tscircuit's 2-point auto-name) |
| `<X>_source_net_<n>` | `X` (per-scope source net) |
| `<X>` | `X` (already clean; multiple scopes share it) |

Any base with **> 1 code** is merged to one canonical net named `<base>`; single-code nets
(VBUS/VBAT/VSYS) are left untouched. Run it on the freshly-exported board, before opening
in KiCad:

```bash
python3 scripts/merge_nets.py index.circuit.kicad_pcb          # dry run (report only)
python3 scripts/merge_nets.py index.circuit.kicad_pcb --write  # apply
```

### `add_cutout_keepouts.py` — keep the router out of the holes

Freerouting will happily route across the tape window, reels, and screw holes. This script
finds every **closed interior** Edge.Cuts shape in the `.kicad_pcb` (`gr_circle`,
`gr_poly`, or `gr_line` loops joined by union-find), leaves the largest (the outer
outline) alone, and writes a per-copper-layer `(keepout …)` rect for each interior hole
into the DSN. The kicad(mm) → DSN(units) transform is derived by matching the outer
Edge.Cuts bbox to the DSN boundary bbox (handles the +100 mm offset, the scale, and the
Specctra Y-flip). Default margin 0.3 mm (`--margin`).

```bash
python3 scripts/add_cutout_keepouts.py index.circuit.kicad_pcb build/index.dsn
```

### `drc_check.py` — triage buckets

`drc_check.py` runs `kicad-cli pcb drc --format json` and **sorts** the violations so a
clean board is obvious and noise can't hide a real defect. It exits non-zero if any
*blocking* issue remains, so it gates the pipeline.

| Bucket | DRC type | Meaning / fix |
|---|---|---|
| **PLACEMENT** | `courtyards_overlap` | parts physically collide — fix `pcbX/pcbY` |
| **ROUTING (real short)** | `shorting_items`, *distinct* base nets | genuine copper short — reroute / move a part |
| **FALSE short** | `shorting_items`, *same* base net | net fragmentation not reconciled — run `merge_nets.py` |
| **ROUTING (other)** | `tracks_crossing`, `track_dangling`, `unconnected` | crossings block; dangling/unconnected reported |
| **EDGE — over the cut** | `copper_edge_clearance`, actual gap ≤ 0.05 mm | copper at/over the board cut — a **real** defect (milled off / shorted to the routed edge) |
| **RULE / FAB / COSMETIC** | `via_diameter`, `annular_width`, silk/mask/text, `clearance`, edge-*near* | global-fix or ignorable (see `apply_fab_rules.py`) |

The real-vs-false short split reuses the same `base_of()` logic as `merge_nets.py`: two
nets with the same base are an unreconciled fragment (false), different bases are a real
short. **Blocking** = placement + real shorts + false shorts + crossings + edge-over-cut.

```bash
python3 scripts/drc_check.py index.circuit.kicad_pcb
```

### `apply_fab_rules.py` — JLCPCB minimums

KiCad's default DRC rules are stricter than any cheap fab, so a perfectly fabbable board
shows "hundreds of violations" that are pure rule-mismatch. These rules live in the
**`.kicad_pro`** project file (not the `.kicad_pcb`), so this patches them there;
`kicad-cli pcb drc` then reads them (reload the project in the GUI to see it there too).

```bash
python3 scripts/apply_fab_rules.py index.circuit.kicad_pro            # default --fab jlcpcb
python3 scripts/apply_fab_rules.py index.circuit.kicad_pro --fab oshpark
```

JLCPCB minimums applied: clearance 0.127 mm, track 0.15 mm, via 0.6 mm / drill 0.3 mm,
copper-edge 0.2 mm, min text 0.25 mm, hole-to-hole 0.5 mm. Cosmetic checks that don't apply
to a generated board (`lib_footprint_mismatch`, silk overlaps, back-layer text, text
height/thickness, mask bridges) are downgraded to `ignore`/`warning` — the *real* checks
(shorts, unconnected, courtyard) are never touched. These numbers mirror the `JLCPCB`
preset in `lib/fab.tsx` (§6).

---

## 6. Fab presets (`lib/fab.tsx`)

`lib/fab.tsx` exports per-fab routing props that make the **generated** geometry legal for
a fab, so `tsci export -f kicad_pcb` needs no KiCad rule cleanup. Spread the preset into
**every** `<board>` *and* `<subcircuit>` (the board-level prop alone won't reach
within-block traces/vias, because each subcircuit autoroutes independently):

```tsx
<subcircuit {...JLCPCB} name="mcu" pcbX={…} pcbY={…}>
```

| Preset | `minTraceWidth` | `defaultTraceWidth` | `viaHoleDiameter` | `viaPadDiameter` |
|---|---|---|---|---|
| `JLCPCB` (default) | 0.15 mm | 0.2 mm | 0.3 mm | 0.6 mm (→ 0.15 mm annular ring) |
| `PCBWAY` | 0.15 mm | 0.2 mm | 0.3 mm | 0.6 mm |
| `OSHPARK` | 0.1524 mm | 0.2032 mm | 0.33 mm | 0.7 mm |

`JLCPCB` is the preset spread throughout flexisette. It pairs with the KiCad-side
`rules/<fab>.kicad_dru` shipped in the `pcb-layout` skill (same numbers, for checking an
already-routed board) and with `apply_fab_rules.py` (§5).

> Watch the via size: tscircuit's `viaPadDiameter` is the via **pad** (0.6 mm), and
> `viaHoleDiameter` is the **drill** (0.3 mm) — giving a 0.15 mm annular ring, above JLC's
> 0.13 mm min.

---

## 7. Make targets

The Makefile (`pcb/Makefile`) wraps the common steps. `make` with no target prints the
help. The targets relevant to *generating and routing* a board:

| Target | What it does |
|---|---|
| `make build` | build the composed board → `dist/` (`tsci build index.circuit.tsx --pcb-only`) |
| `make modules` | build every block standalone (`tsci build modules/*.circuit.tsx --disable-parts-engine --pcb-only`) |
| `make outline` | the placement gate — flag parts off the outline / in a cutout (`outline-check.mjs`) |
| `make routecheck [MODS="mcu audio"]` | the measured loop: per-block **UNROUTED** count + build **TIME** + PASS (`routecheck.sh`) |
| `make freeroute [FILE=…]` | route a board standalone with Freerouting → `.ses` (`freeroute.sh`) |
| `make export` | hand off to KiCad for hand-routing — placement + pours + ratsnest (`tsci export -f kicad_pcb index.circuit.tsx`) |
| `make dev [FILE=…]` | live tscircuit viewer at https://localhost:3020 |

`make routecheck` is the convergence metric for the modular flow: it builds each module
under a timeout (`TIMEOUT`, default 120 s) and reports, per block, the **UNROUTED** count
(`grep -c 'Could not find a route'` — the log is ground truth, not trace counts), the wall
**TIME**, and PASS (unrouted == 0 *and* clean exit). Drive UNROUTED → 0 and TIME down by
refining placement.

```bash
make modules                       # build every block standalone
make routecheck                    # all modules — unrouted + time per block
make routecheck MODS="mcu audio"   # a subset
make outline                       # placement gate before routing
make freeroute                     # standalone Freerouting on index.circuit.tsx
make export                        # KiCad handoff for hand-routing
```

The full automated route (export → reconcile → keepout → Freerouting → IPC-inject → DRC)
is **`bash scripts/route.sh`**, *not* a make target (see §3).

> **Related, out of scope here:** the round-trip floorplan loop (`make place` / `make sync`
> / `make variant`) and the auto-orient pass (`make untangle`) are documented in
> `docs/placement.md`; Gerbers/drill/BOM/CPL (`make fab`) in `docs/fabrication.md`; and the
> 3D enclosure fit-check (`make fit`) in the `pcb-enclosure-fit` skill.

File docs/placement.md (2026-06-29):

# Placement — the fast early-design loop

The north star of the whole PCB effort: **routing difficulty is decided at placement time, and every
autorouter is immature.** So the time goes into placement, and the tooling here makes placement *fast*
(visual, round-trippable), *reproducible* (positions as data), *variant-able* (a layout per release),
and *cheap to untangle* (an automatic rotation pass). Routing itself is in [pcb-toolchain.md](pcb-toolchain.md).

## Positions are data

A board's floorplan lives in **`pcb/placement/<variant>.json`** — not buried in `.tsx` `pcbX/pcbY`
literals. One object per part:

```json
{ "U1": { "x": -38, "y": 2, "rot": 0, "side": "top" }, ... }
```

- Coordinates are in the **tscircuit-centred design frame** (board centred at origin, Y-up). The
  KiCad↔design transform is derived from the board-outline bbox centre (for this board, (100,100), so
  `tx = kx−100, ty = 100−ky`). `rot` is degrees (0/90/180/270); `side` is `top`/`bottom`.
- `placement/default.json` is the current working floorplan. A **variant** is just another file
  (`placement/glow.json`); same circuit, different layout — the clean way to ship a unique board per drop.
- **SIDE lives in code** (`layer=` on the part); the round-trip only carries x/y/rot. A hand flip needs
  footprint mirroring — keep that in the `.tsx`.
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

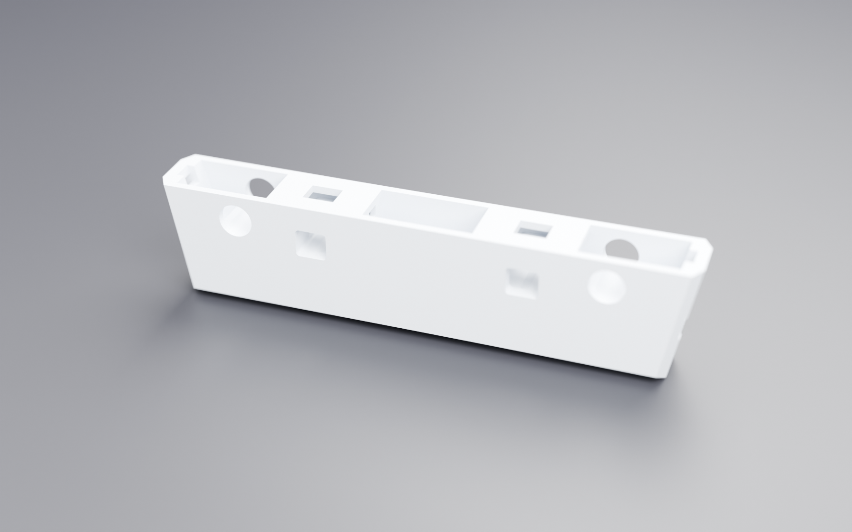
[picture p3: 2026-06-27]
render/out/flexisette_insert.png

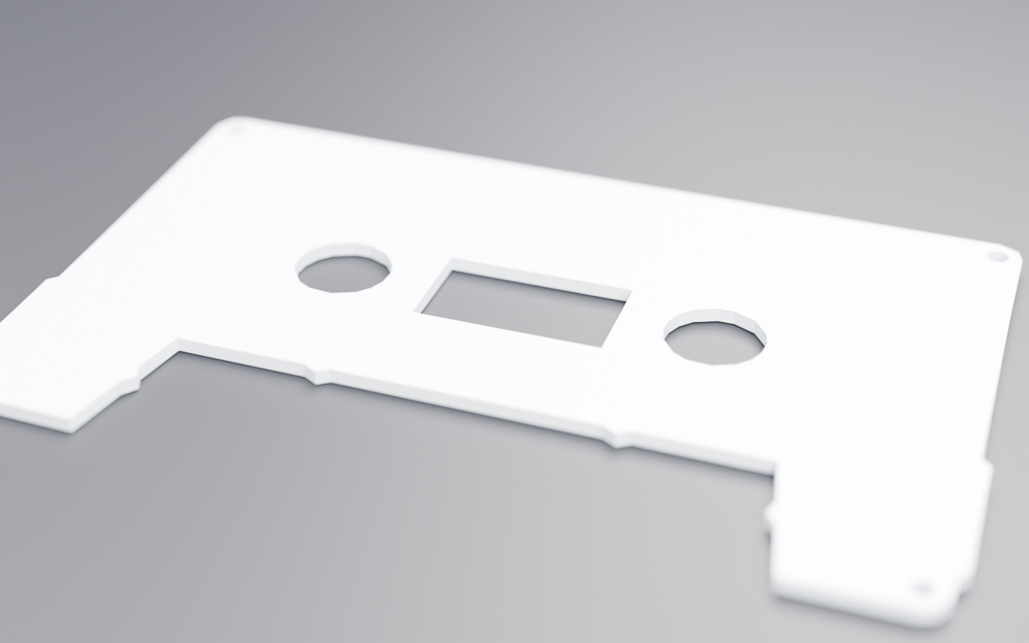
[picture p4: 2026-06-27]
render/out/flexisette_panel.png

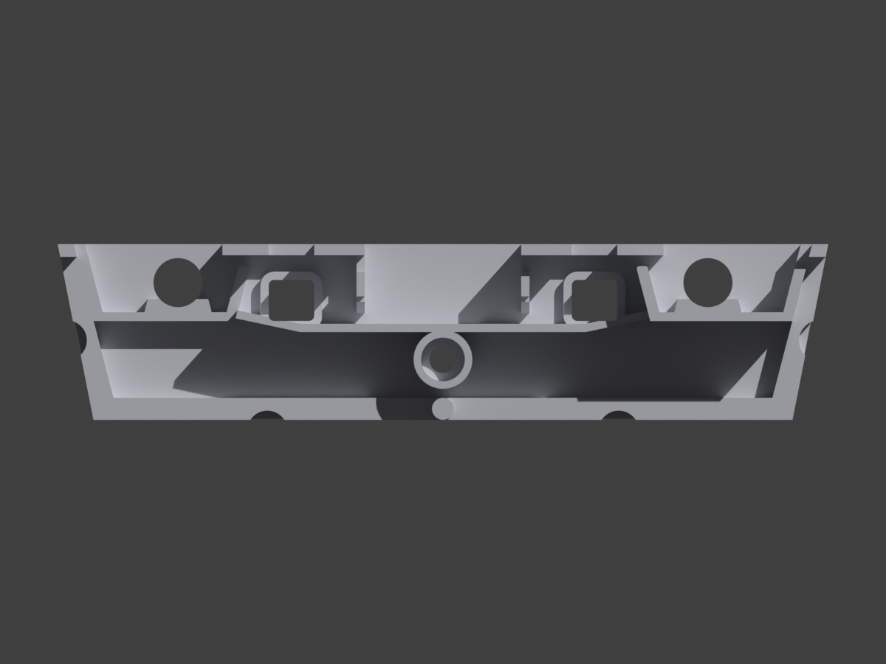
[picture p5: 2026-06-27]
assets/cassette-shell-minecraft/insert-front.png

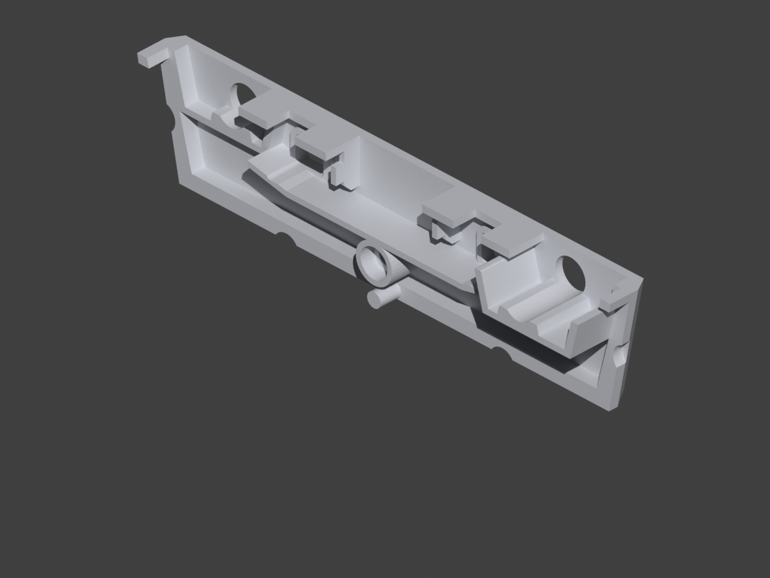
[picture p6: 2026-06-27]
assets/cassette-shell-minecraft/insert-persp.png

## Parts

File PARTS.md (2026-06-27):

# flexisette — Master Parts List (sourced 2026-06)

Consolidated from the component sourcing pass. Prices are indicative single-unit unless noted; pull live break pricing at order time. **Bold** = recommended pick for the frozen engine. Distributor stock moves fast — re-verify before a BOM lock.

Envelope reference: compact-cassette **~100.5 × 64 × 12 mm**; visible front face ~64 × 100 mm; usable PCB outline inside the shell ~98 × 62 mm.

---

## 1. MCU / SoC

| Part | Key spec | Source | ~Price (1 / vol) |
|---|---|---|---|
| **ESP32-S3-WROOM-1-N16R8** | 2×LX7 @240MHz, 16MB flash, **8MB Octal PSRAM**, BLE5, 2×I²S, QSPI LCD, 14× cap-touch, native USB | LCSC C2913202 / DigiKey | **$5.41 / $3.66** |
| ESP32-S3-WROOM-1-N8R8 | 8MB flash / 8MB Octal PSRAM | LCSC | ~$4.70 / $3.37 |
| ESP32-S3-WROOM-1U-N16R8 | external-antenna variant (for metal/shielded shell) | DigiKey | — |
| ESP32-S3R8 (bare) | 8MB Octal PSRAM in-package, no flash | LCSC C2913194 | $2.23 |
| ESP32-P4NRW32 + ESP32-C6-MINI-1-N4 | RISC-V @400MHz, 2D/JPEG accel, MIPI-DSI, 32MB PSRAM — **NO radio**, add C6 for BLE | LCSC C22387510 / C5736265 | $5.87 + $2.51 |
| RP2350A (+ Pico 2 W) | 2×M33 @150 + FPU/DSP, QSPI PSRAM; radio via CYW43439 (immature BLE) | LCSC C42411118 | $1.10 / $0.80 |
| nRF52840 / nRF5340 | best low-power BLE, weak for media (no PSRAM) — **BLE co-processor only** | DigiKey | $6.78 / $9.74 |

**Pick:** ESP32-S3-WROOM-1-N16R8 — the only single chip that does software audio decode + live visuals + game + BLE. Octal PSRAM is the enabler. Pin decode → core 0, visuals → core 1.

## 2. Display — MOTION path (rigid color)

| Part | Size / res | Controller / IF | Source | ~Price |
|---|---|---|---|---|
| **1.91" QSPI AMOLED** | 240×536 letterbox (tape-window) | RM67162 / QSPI | LILYGO T-Display-S3 AMOLED / Waveshare ESP32-S3-AMOLED-1.91 | **~$30** (dev board); bare FPC panel sourceable |
| 2.0" SPI IPS (budget fallback) | 240×320 | ST7789 / SPI | Adafruit #4311 / Waveshare | $14–20 |
| 1.9" SPI IPS | 170×320 letterbox | ST7789V2 / SPI | Waveshare | $12–13 |
| 2.41" QSPI AMOLED | 450×600 full-face | RM690B0 / QSPI | Waveshare ESP32-S3-Touch-AMOLED-2.41 | ~$45–50 |
| 1.8" QSPI AMOLED | 368×448 | SH8601 / QSPI | Waveshare / Makerfabs | $36–43 |
| 1.28" round LCD ("reel") | 240×240 | GC9A01 / SPI | Waveshare / Adafruit #6178 | $5–15 |
| 1.43" round AMOLED ("reel") | 466×466 | CO5300 / QSPI | Waveshare | $39–43 |
| 2.4" SPI IPS | 240×320 biggest cheap face | ILI9341/ST7789 / SPI | Waveshare | $14–15 |

**Avoid:** bare MIPI-DSI AMOLED panels — not drivable from ESP32-S3 (would require ESP32-P4).
**Pick:** 1.91" RM67162 QSPI AMOLED — tape-window shape, emissive, ~1mm thin, 60Hz tear-free w/ TE line.

## 3. Display — STATIC / FLEXIBLE path (e-paper)

| Part | Size / res | Notes | Source | ~Price |
|---|---|---|---|---|
| **2.9" flexible e-paper** | 296×128 **mono**, flexible (~10mm bend R) | full ~3s / partial ~0.3s; holds image at 0W; FPC tail must stay flat | Adafruit #4262 / Waveshare 2.9 e-Paper D / Pimoroni | **~$25** |
| 2.13" flexible e-paper | 212×104 mono, flexible | same tech, smaller | Crystalfontz CFAP104212D1-0213 / Waveshare | $17 |
| 4" Spectra 6 color (**rigid**) | 600×400, 6-color | static stills, ~19s/frame, **no partial**, rigid glass | Waveshare 4" e-Paper (E) | $52.99 |
| Driver board (if not integrated) | — | UC8151/IL0373 controller | Adafruit eInk Breakout #4224 / Waveshare HAT | — |

**Reality:** flexible color e-paper & small flexible OLED are **not buyable** in maker qty in 2026. Flexible = mono + slow + static only (no motion/game). Use only for a special "static edition" drop.

## 4. Audio — amp / DAC / speaker

| Part | Function | Source | ~Price |
|---|---|---|---|
| **MAX98357A** | mono I²S Class-D amp + DAC (no MCLK, 3 wires) | LCSC C910544 / Adafruit #3006 | **$1.34 / $5.95** |
| NS4168 | I²S Class-D, MAX98357A cost-down | LCSC C910588 | $0.38 |
| AW88298 | I²S smart amp + boost (louder off 1 cell) | LCSC C5162557 | $0.6–1 |
| TAS2505 | I²S speaker amp **+ headphone driver + DSP/EQ** (covers both out paths in one chip) | TI | — |
| **PCM5102A** | I²S DAC, 112dB, PLL 3-wire → line/HP out | LCSC C107671 / Adafruit #6250 | **$0.65 / $4.95** |
| CS4344 | cheap I²S DAC (needs MCLK) | LCSC C8952 | $0.41 |
| **Adafruit Mini Oval #3923** | speaker 30×20×**5mm**, 8Ω 1W | Adafruit | **$1.95** |
| Same Sky CMS-151125-078S | speaker 15×11×**2.5mm** (lowest profile) | Same Sky | $1–2 |
| Adafruit Bone Conductor #1674 | shell-as-diaphragm exciter (dodges speaker-box problem) | Adafruit | ~$8 |

**Decode (software, free):** ESP32-audioI2S (Helix MP3 + faad2 AAC), ESP8266Audio, libhelix, esp-adf. Target: MP3 ≤320k + AAC-LC real-time; Opus/Vorbis OK with PSRAM.
**Pick:** MAX98357A → Mini Oval for onboard sound; PCM5102A → 3.5mm jack, share one I²S bus, jack-detect mutes the amp.

## 5. Storage (content packs)

| Part | Cap | Type | Source | ~Price |
|---|---|---|---|---|
| W25Q256JV | 32MB | QSPI NOR, XIP | LCSC C2682312 | $5.18 |
| **W25Q512JV** | 64MB | QSPI NOR, XIP (~2h Opus) | LCSC C7389628 | **$9.60** |
| W25N01GV | 128MB | SPI NAND (needs FTL/littlefs) | DigiKey | $3.57 |
| **GCT MEM2075** | — | microSD socket, **1.40mm** push-push | DigiKey | **$1.38** |
| Hirose DM3AT-SF-PEJM5 | — | microSD socket, 1.68mm workhorse | DigiKey | $2.06 |

Capacity ref: MP3 128k ≈ 1MB/min; Opus 64k ≈ 2min/MB. One rich drop ≈ 25–50MB.
**Two coherent paths:** (1) **microSD-as-cartridge** (GCT MEM2075, SPI mode) = the cassette-swap ritual + trivial PC authoring; (2) **sealed W25Q512 NOR** = rugged, XIP, USB-C/Wi-Fi updates. Skip NAND unless carrying many packs resident.

## 6. NFC

| Mode | Part | Notes | Source | ~Price |
|---|---|---|---|---|
| Passive tag | NTAG213 inlay | tap→URL, no MCU pin; 144B | shopNFC / Seritag | €0.10–0.40 |
| Passive auth | NTAG 424 DNA inlay | AES-128 + SUN, clone-proof, app-free | shopNFC / GoToTags | €0.60–1.29 |
| **Connected** | **NTAG I²C plus 2k (NT3H2211)** | MCU writes via I²C, phone reads; 64B pass-through SRAM; **5mA harvest / tap-to-wake**; 50pF (easy flex coil) | LCSC C710403 / DigiKey | **$0.73** |
| Connected (big mem) | ST25DV64K-IER6T3 | 8KB EEPROM, 256B mailbox, 1MHz I²C, ISO15693 | LCSC C1852797 | $1.62 |
| Reader / P2P | ST25R3916B | reader + card-emu + **cassette-to-cassette P2P**; auto antenna tuning (fixes flex detune) | DigiKey | $5.98 |
| Reader (cheap) | PN532 module | battle-tested libs | Elechouse | ~$22 |
| Antenna ferrite | Würth WE-FSFS 364004 / TDK IFL04-100NB300X200 | between coil & LiPo (prevents detune) | DigiKey | $13 / $18 |

Antenna: single-layer etched coil on flex, **no ground pour behind it**, ferrite film toward the LiPo, C0G trim-cap footprint. App notes: NXP AN11276, ST AN2972, NXP NFC Antenna Design Hub.
**Pick:** NTAG I²C plus 2k. Upgrade to NTAG 424 DNA (authenticity), ST25DV64K (payloads), or ST25R3916B (tap-to-tap).

## 7. Battery (1S LiPo, slim)

| Cell | Dim T×W×L (mm) | Cap | Source | ~Price | Note |
|---|---|---|---|---|---|
| **PKCell LP503562** | **5.0 × 34 × 62** | 1200mAh | Adafruit #258 / PKCell | **$9.95** | best fit, ~7–9h, PCM included |
| PKCell LP503035 | 5.0 × 30 × 35 | 500mAh | Adafruit #1578 | $7.95 | for the slim build, ~3h |
| spec-order LP504050/505060 | 4.5–5.0 × ~50 × ~60 | ~1500–1800mAh | PKCell / AliExpress | $5–9 | verify datasheet |

**Avoid (too thick, >5mm):** Adafruit #2011 (7mm), PKCell LP803860 (8mm).
Safety: confirm cell ships **with PCM**, or add DW01+FS8205. Charge CC/CV ≤0.5–1C.

## 8. Power management

| Part | Function | Source | ~Price |
|---|---|---|---|
| **MCP73831T-2ATI/OT** | 500mA single-cell charger, SOT-23-5 | LCSC C14879 | **$0.50** |
| BQ24074RGTR | charger **with power-path** (runs while charging / dead battery) | LCSC C54313 | $0.63 |
| TP4056 | 1A charger, cheapest (**no protection** — needs cell PCM) | LCSC C382139 | $0.066 |
| **AP2112K-3.3 / ME6211** | 3.3V LDO (no boost needed; amp+backlight off VBAT) | LCSC | ~$0.05–0.10 |
| TYPE-C-31-M-12 | USB-C connector (16-contact SMD) + **2× 5.1kΩ CC pulldowns** | LCSC C165948 | $0.097 |
| MAX17048 | fuel gauge (optional; else read VBAT via ADC) | LCSC C2682616 | $1.38 |

USB-C wires to ESP32-S3 **native USB** (GPIO19/20) — no CP2102/CH340 bridge needed.

## 9. Interconnect (engine ↔ flex J-card)

| Approach | Stack height | Swap per drop | Source | ~Price |
|---|---|---|---|---|
| **0.5mm FFC/FPC ZIF** | **~0.9–1.2mm** | trivial (flip latch) | Kyocera 6277 / JAE FF03 / Hirose FH12 / generic | $0.11–0.17 |
| Hirose DF40 mezzanine, 0.4mm | 1.5–4.0mm | plug/unplug (needs FR4 backer on flex) | LCSC DF40C series | $0.15–0.76 |
| Solder flex tail direct | ~0.2mm | none (desolder) | — | ~$0 |

**Pick:** 0.5mm FFC/FPC ZIF — lowest profile that's still hand-swappable. Flex tail needs a 0.2–0.3mm stiffener at the contacts.

## 10. PCB / flex fabrication

| Fab | Product | Notes | ~Cost |
|---|---|---|---|
| **JLCPCB flex** | 1–2L plain flex, ENIG gold, yellow/black coverlay, white silk | 5pc MOQ, 4–5 day; NFC coil + cap-touch = free copper | **~$1–3/unit @50–100** |
| PCBWay | flex + **rigid-flex**, more colors, impedance | rigid-flex from ~$1500/5pc (low qty) | — |
| OSH Park flex | 2L flex, US ENIG gold | ~21 day, multiples of 3 | $15/sq-in (3 copies) |

**Engine = normal rigid FR4. J-card = plain JLCPCB flex. Avoid rigid-flex at drop quantities** (5–10× cost vs flex + connector).

## 11. Tape head (reverse cassette-adapter playback)

Use case: drive a small tape head with audio so a real deck's playback head magnetically couples to it ("cassette adapter in reverse"). Mono is fine. No bias circuitry — just AC audio into the coil.

| Source | What you get | ~Price | Where |
|---|---|---|---|
| **Harvest a wired cassette→3.5mm adapter** ← best bet | sprung, correctly-positioned head **+ dummy-reel/auto-stop gear + spring** in one teardown | **$7–9** | DIGITNOW (Amazon B081DVQN9Z), Reshow (B07FKFMRGF), Arsvita (B07N2KPTGW), Aluratek $9.99 |
| AliExpress bare head (current production) | new stereo/mono play/record head, often on an L-bracket w/ leads; 200–300Ω | $4–8 | aliexpress "cassette tape heads"; DYNY62 240Ω, mono 3-pack ~$7.80 ea |
| Amazon Toyvian bare head | dual-channel head, fast US shipping | ~$8 | Amazon B0CXQPMJ76 |
| eBay / VintageAudioCart RH-M-01 | NOS mono ferrite head (thin stock) | ~$6 | ebay Tape-Recorder-Head category |
| **Avoid** | TASCAM/JRF/Nortronics pro deck heads | $160+ | overkill |

**Driving it:** head is low-Z (~200–600Ω DC, ~10mH record / ~100–150mH play); drive like a tiny voice coil from a small amp (**PAM8403 / LM386**) or even the PCM5102A line-out buffered. Play vs record head doesn't matter (reciprocal); stereo head → wire gaps in parallel or drive one for mono. **No HF bias needed.**

**Why harvest wins:** the adapter *is* a reverse-cassette device already — head + spring + the auto-stop-defeating gear train are exactly what Spec A's 3D-printed bottom-edge module needs. Buy 2–3 (leads are fragile on teardown). New heads are still made in China (same supply chain as FiiO CP13 / We Are Rewind decks), so "new production" is real, not just NOS.

**The user has some of these already on hand** — check those first before ordering.

---

## Recommended frozen-engine stack (one line)
ESP32-S3-WROOM-1-N16R8 · 1.91" RM67162 QSPI AMOLED · MAX98357A + Mini Oval speaker · PCM5102A + 3.5mm jack · microSD (GCT MEM2075) or W25Q512 NOR · NTAG I²C plus 2k · PKCell LP503562 1200mAh · MCP73831 + AP2112K-3.3 + USB-C native · 0.5mm FFC/ZIF to a JLCPCB plain-flex J-card.

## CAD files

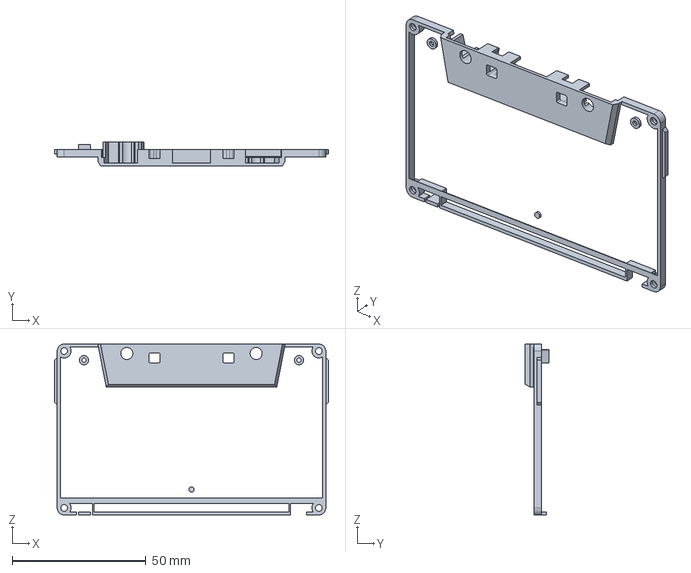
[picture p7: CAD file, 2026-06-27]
assets/cassette-shell/assembled.FCStd
102.3 x 8.80 x 63.8 mm

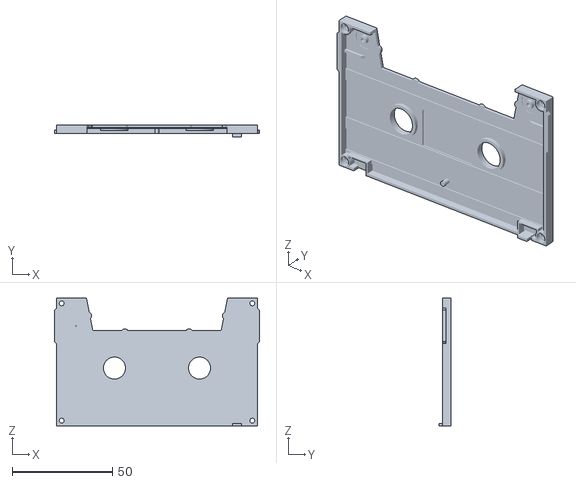
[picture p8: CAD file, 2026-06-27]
assets/cassette-shell-minecraft/Minecraft/beta-side-1.stl
102.2 x 6.15 x 63.8

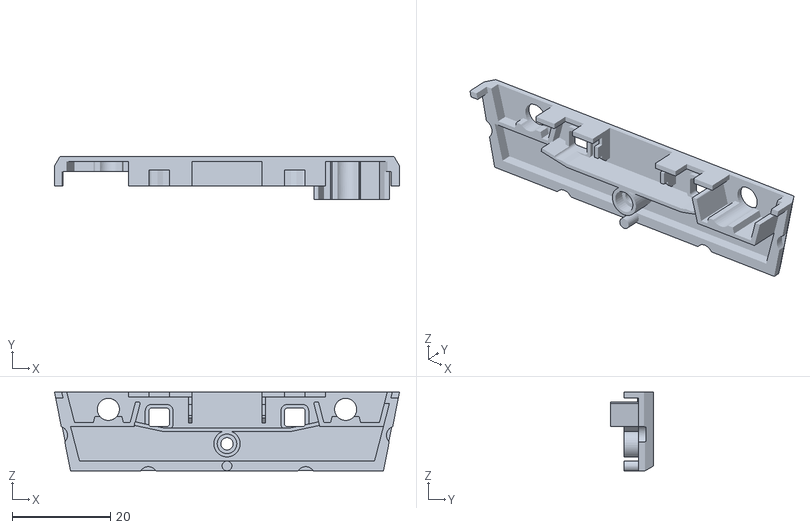
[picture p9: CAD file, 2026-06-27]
assets/cassette-shell-minecraft/side-1-insert.stl
70.2 x 8.80 x 16.0

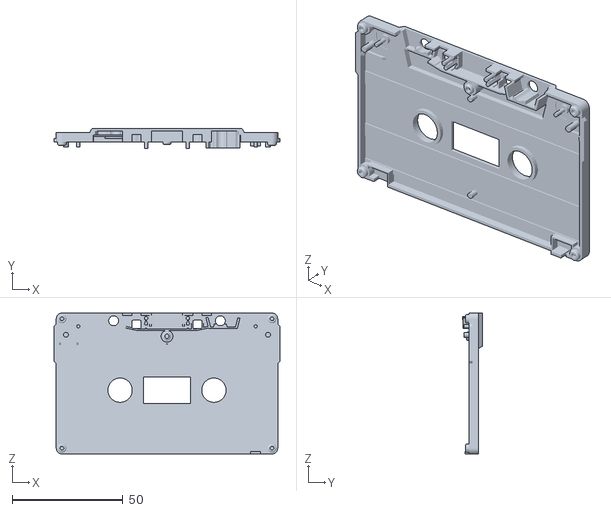
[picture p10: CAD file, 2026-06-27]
assets/cassette-shell/cassette_tape_-_side_b.stl
102.2 x 9.05 x 63.8

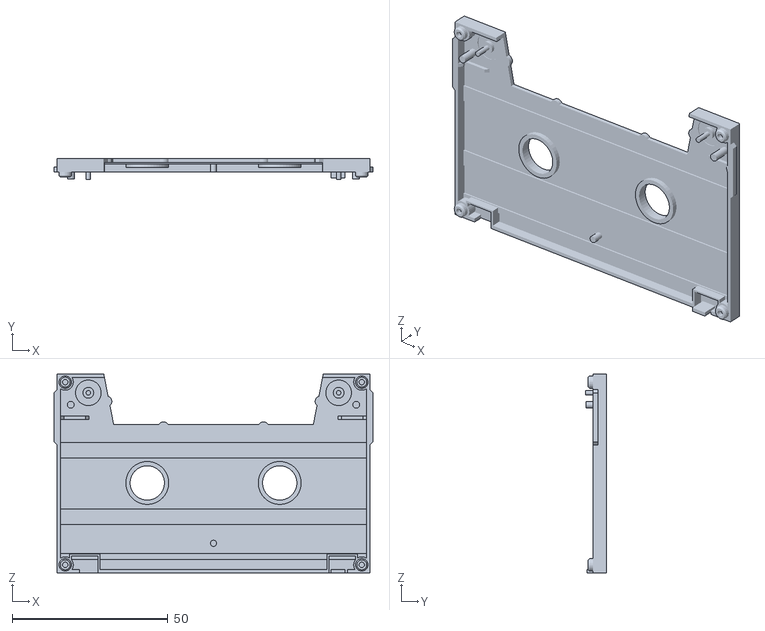
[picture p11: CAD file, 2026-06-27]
assets/cassette-shell-minecraft/Minecraft/alpha-side-1.stl
102.2 x 6.68 x 63.8

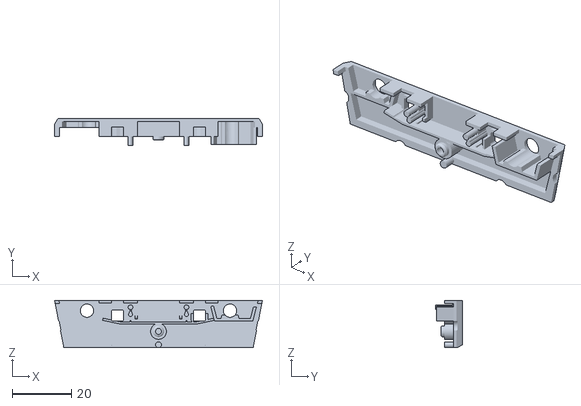
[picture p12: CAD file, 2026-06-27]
assets/cassette-shell-minecraft/side-2-insert.stl
70.2 x 9.05 x 16.0

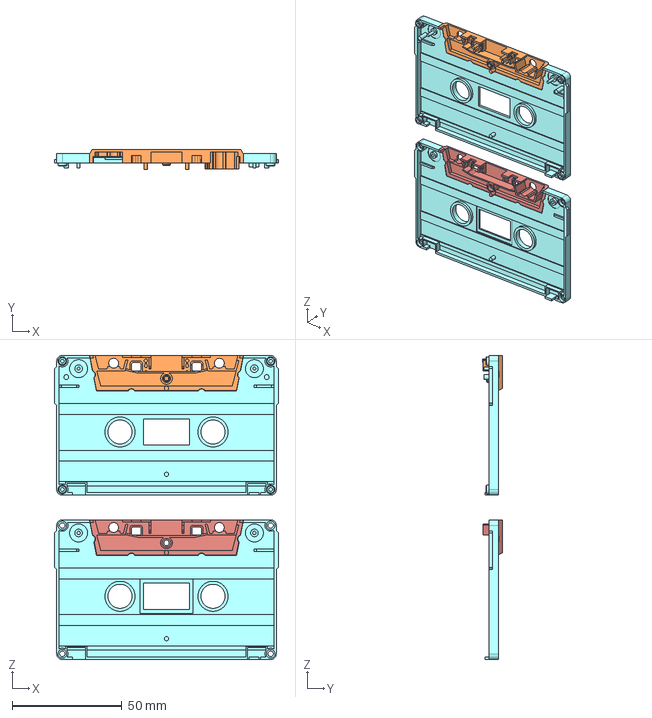
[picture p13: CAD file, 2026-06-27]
assets/cassette-shell-minecraft/cassettes-remix.step
102.2 x 9.05 x 138.8 mm

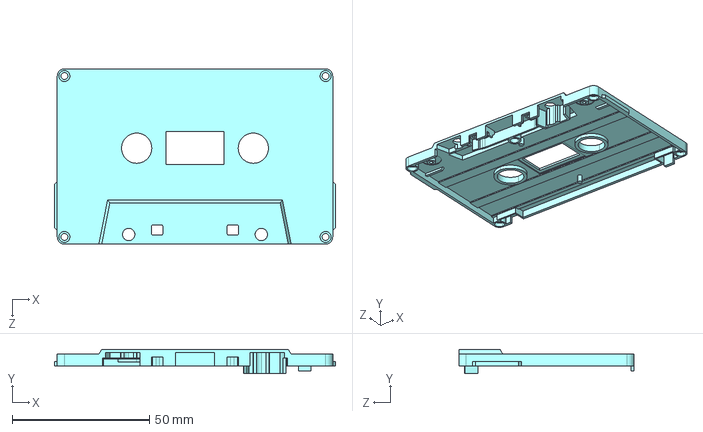
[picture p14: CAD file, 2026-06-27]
assets/cassette-shell/cassette_tape_-_side_1.step
102.3 x 8.80 x 63.8 mm

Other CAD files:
assets/cassette-shell/cassette_tape_-_side_2.step
assets/cassette-shell-minecraft/Minecraft/alpha-side-2.stl
assets/cassette-shell-minecraft/Minecraft/beta-side-2.stl
assets/cassette-shell-minecraft/side-2-plain.stl
assets/cassette-shell-minecraft/side-1-plain.stl
assets/cassette-shell/cassette_tape_-_side_a.stl
assets/cassette-shell/assembled.stl
render/out/flexisette_assembly.blend
render/out/flexisette_frame.blend

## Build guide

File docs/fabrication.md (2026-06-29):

# Fabrication — Gerbers, assembly, and DFM

Turning the routed board into something JLCPCB will build. Generation is one command; the rest is
knowing what the fab does and doesn't check.

## One command

```
make fab        # in pcb/
```

Produces, in `pcb/fab/` (gitignored):

| file | what | from |
|---|---|---|
| `flexisette_jlcpcb.zip` | Gerbers (all layers) + Excellon drill | `kicad-cli pcb export gerbers` + `… drill` |
| `bom.csv` | assembly BOM: Comment, Designator, Footprint, LCSC Part # | `scripts/gen_bom_cpl.py` ← `dist/index/circuit.json` |
| `cpl.csv` | placement (pick-and-place): Designator, Mid X/Y, Layer, Rotation | `scripts/gen_bom_cpl.py` ← `kicad-cli pcb export pos` |
| `bom_unassigned.csv` | parts with **no** LCSC number (hand-assemble) | same |

`gen_bom_cpl.py` reads the **LCSC part numbers tscircuit resolved from the imports** (29/30 parts carry
one; it takes the first/preferred of each part's candidate list — the JLC UI flags Basic vs Extended so
you can swap). Parts with no LCSC (the OLED module) go to `bom_unassigned.csv` rather than being dropped
silently. The CPL comes from `kicad-cli pcb export pos`, in the **same coordinate origin as the Gerbers**,
so JLC aligns them automatically.

## Uploading to JLCPCB

1. **jlcpcb.com → Order now** (or **Add Gerber File**; or the standalone **Gerber Viewer** to just look).
2. Upload **`flexisette_jlcpcb.zip`** (the zip itself). It auto-detects 2 layers + the ~102×64 mm size.
3. **Check the preview** — confirm the interior cutouts (OLED window, 2 reels, 4 screw holes) render as
   openings (JLC reads them from `Edge_Cuts.gm1`; internal cutouts sometimes need a confirm/fee/note).
4. For **assembly** (parts soldered): also upload `bom.csv` + `cpl.csv` in the SMT step. Expect to nudge
   a few part rotations (KiCad↔JLC rotation conventions differ); JLC's preview lets you.

## What JLC's DFM does — and doesn't — catch

The DFM check is **manufacturability** (can we build this copper: trace/space mins, hole sizes, annular
rings, board-edge clearance). It is **NOT a netlist/connectivity check** — it will faithfully fabricate
an *unrouted* net as open. So **passing DFM ≠ the board works**.

A subtle, important point: **JLC's DFM reads the raw Gerbers and ignores your `.kicad_pro` rules.**
`apply_fab_rules.py` downgrades cosmetic checks so KiCad's own DRC is readable, but that changes nothing
about what JLC sees. The DFM is the real fab gate; KiCad DRC (`drc_check.py`) is for triage.

## flexisette's DFM status

From an actual JLC PCB-DFM run on the current board:

- **Clean / structural ✓** — *trace-to-board-edge* is Good (the U1 re-floorplan fixed earlier edge
  spills), plus trace width, pad spacing, soldermask bridge, via-in-pad.
- **Real, deferred to a production pass:**
  - **PTH → trace, 0.04 mm (Danger ×3):** `GND`/`VBUS` traces hugging the USB-C mounting holes — reroute.
  - **Pad → board-edge, 0.07 mm (Danger ×2):** two pads tight to an edge/cutout — locate in the GUI + nudge.
  - The **~10 unconnected nets** (the decoupling-cap cluster + DIN) — the genuine routing tail.
- **Loud but auto-handled (accept):** silkscreen-on-pad / -on-hole and 0.1 mm silk line width — JLC
  auto-trims silk off pads and prints thin lines; cosmetic. Annular-ring and trace-spacing warnings are
  within JLC capability.

**Bottom line:** the board is **prototype-ready** (order it for a fit/mechanical check), but a working
production board wants the routing tail finished + the two USB-C-area dangers fixed. Tracked in
[roadmap.md](roadmap.md).

## Fab rules

`scripts/apply_fab_rules.py <board.kicad_pro> [--fab jlcpcb]` sets the project's net-class clearances +
design rules to a fab's real minimums (JLCPCB: 0.127 mm clearance, 0.15 mm track, 0.6/0.3 via, 0.2 mm
copper-edge, 0.25 mm min text) and downgrades non-fab cosmetic checks. The same numbers live in
`lib/fab.tsx` (the `JLCPCB` props spread onto every board/subcircuit). KiCad's default rules are stricter
than any cheap fab, so without this a perfectly fabbable board shows "hundreds of violations."

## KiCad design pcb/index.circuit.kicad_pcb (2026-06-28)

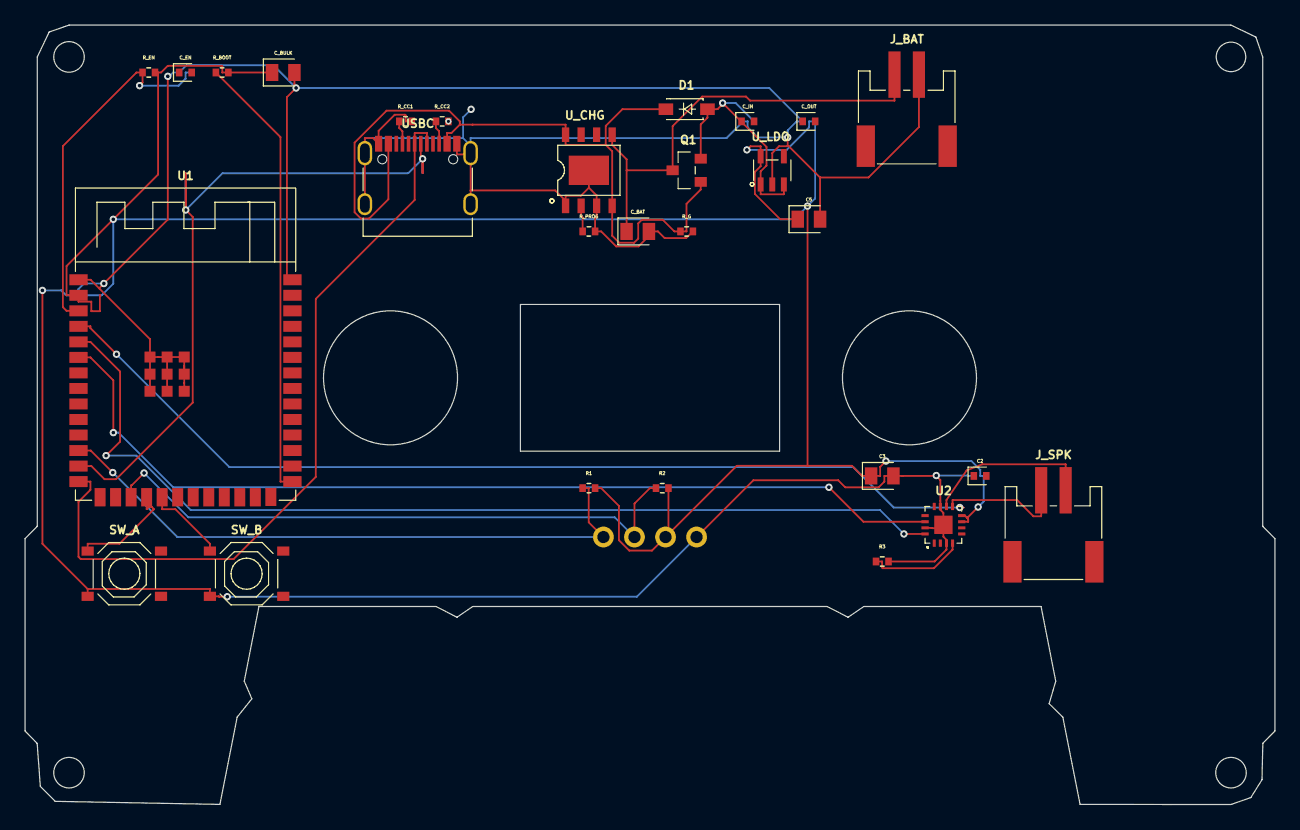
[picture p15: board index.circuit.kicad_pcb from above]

Board: 2 copper layers, 102.2 x 63.8 mm, 30 parts (0 on the bottom side), 22 nets.

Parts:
C1, C2: 100nF; capacitor_0402
C3: 10uF; capacitor_0805
C5: 22uF; capacitor_0805
C_BAT: 10uF; capacitor_0805
C_BULK: 22uF; capacitor_0805
C_EN: 100nF; capacitor_0402
C_IN: 1uF; capacitor_0402
C_OUT: 1uF; capacitor_0402
D1: D; B5819W_SL
J_BAT: S2B_PH_SM4_TB_LF__SN_; S2B_PH_SM4_TB_LF_SN
J_SPK: S2B_PH_SM4_TB_LF__SN_; S2B_PH_SM4_TB_LF_SN
OLED: chip
Q1: AO3401A
R1, R2: 4.7kΩ; resistor_res0402
R3: 100kΩ; resistor_res0402
R_BOOT: 10kΩ; resistor_res0402
R_CC1, R_CC2: 5.1kΩ; resistor_res0402
R_EN: 10kΩ; resistor_res0402
R_G: 100kΩ; resistor_res0402
R_PROG: 2kΩ; resistor_res0402
SW_A: TS_1187A_B_A_B
SW_B: TS_1187A_B_A_B
U1: ESP32_S3_WROOM_1_N16R8
U2: MAX98357AETE_T
USBC: TYPE_C_31_M_12
U_CHG: TP4056_42_ESOP8
U_LDO: ME6211C33M5G_N

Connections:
BCK: U1.5, U2.16
DIN: U1.7, U2.1
GND: C1.2, C2.2, C3.2, C5.2, C_BAT.2, C_BULK.2, C_EN.2, C_IN.2, C_OUT.2, J_BAT.2, OLED.1, R3.2, R_CC1.2, R_CC2.2, R_G.2, R_PROG.2, SW_A.3, SW_B.3, U1.1, U1.40, U1.41, U1.42, U1.43, U1.44, U1.45, U1.46, U1.47, U1.48, U1.49, U2.3, U2.11, U2.15, U2.17, USBC.1, USBC.2, USBC.3, USBC.4, USBC.13, USBC.14, U_CHG.1, U_CHG.3, U_CHG.9, U_LDO.2
SCL: OLED.3, R2.1, U1.17
SD: R3.1, U1.4, U2.4
SDA: OLED.4, R1.1, U1.12
U1.EN to R_EN.pin1: C_EN.1, R_EN.1, U1.3
U1.IO0 to R_BOOT.pin1: R_BOOT.1, U1.27
U1.IO10 to SW_A.A: SW_A.1, U1.18
U1.IO11 to SW_B.A: SW_B.1, U1.19
U2.OUTN to J_SPK.pin2: J_SPK.2, U2.10
U2.OUTP to J_SPK.pin1: J_SPK.1, U2.9
USBC.A5 to R_CC1.pin1: R_CC1.1, USBC.6
USBC.B5 to R_CC2.pin1: R_CC2.1, USBC.12
USB_DM: U1.13, USBC.7, USBC.9
USB_DP: U1.14, USBC.8, USBC.10
U_CHG.PROG to R_PROG.pin1: R_PROG.1, U_CHG.2
V3V3: C1.1, C2.1, C3.1, C5.1, C_BULK.1, C_OUT.1, OLED.2, R1.2, R2.2, R_BOOT.2, R_EN.2, U1.2, U2.7, U2.8, U_LDO.5
VBAT: C_BAT.1, J_BAT.1, Q1.3, U_CHG.5
VBUS: D1.1, Q1.1, R_G.1, USBC.15, USBC.16, U_CHG.4, U_CHG.8
VSYS: C_IN.1, D1.2, Q1.2, U_LDO.1, U_LDO.3
WS: U1.6, U2.14

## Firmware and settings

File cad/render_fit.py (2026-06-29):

"""render_fit.py — 3D fit-check of the routed PCB against the printed cassette parts.

Stacks the REAL board (cad/build/pcb.stl, from import_pcb.py) with the printed spacer frame,
top panel, and head insert at the machine_params Z datums, and renders two OpenSCAD views:
  build/fit_iso.png  — exploded iso (layers read apart, board cutouts vs frame visible)
  build/fit_top.png  — straight top-down (window/reels/screws alignment check)

This is the placement-time 3D check: connector/window/reel positions on the board are only
right if they line up with the printed shell openings. Run it after each place/route pass:
    py/bin/python cad/import_pcb.py && py/bin/python cad/render_fit.py
"""
import os, subprocess, sys
import machine_params as M

HERE = os.path.dirname(os.path.abspath(__file__))
B = os.path.join(HERE, "build")
PCB_T, GAP = M.PCB_T, M.SPACER_GAP
TOP_Z = PCB_T + GAP                       # top layer datum (== machine.py)

LAYERS = [   # (stl, z_mm, [r,g,b], explode_factor)
    ("pcb.stl",   0.0,    [0.10, 0.45, 0.20], -1.0),   # real board (green) — bottom
    ("frame.stl", PCB_T,  [0.62, 0.63, 0.66],  0.0),   # printed spacer frame (grey)
    ("panel.stl", TOP_Z,  [0.83, 0.34, 0.06], +1.0),   # printed top panel (warm)
]


WIN = (0, 3)   # tape-window centre in the render frame (board cutout + cad share it)


def oled_lines(zbase):
    """0.96\" SSD1306 module behind the board at the window: blue module PCB + dark screen (screen on +Z)."""
    o, s = os.path.join(B, "oled.stl"), os.path.join(B, "oled_screen.stl")
    if not os.path.exists(o):
        return []
    return [f'color([0.10,0.20,0.55]) translate([{WIN[0]},{WIN[1]},{zbase:.3f}]) import("{o}");',
            f'color([0.04,0.04,0.07]) translate([{WIN[0]},{WIN[1]},{zbase:.3f}]) import("{s}");']


def scad(explode):
    lines = ["$fn=48;"]
    for stl, z, c, ef in LAYERS:
        p = os.path.join(B, stl)
        if not os.path.exists(p):
            continue
        lines.append(f'color([{c[0]},{c[1]},{c[2]}]) translate([0,0,{z + ef*explode:.3f}]) import("{p}");')
    lines += oled_lines(LAYERS[0][1] - 4 - 2 * explode)   # OLED just behind the board (screen at the window); explodes down
    ins = os.path.join(B, "insert.stl")          # head insert: thickness->Z, head face -> -Y, front edge
    if os.path.exists(ins):
        lines.append(f'color([0.45,0.06,0.06]) translate([0,{-M.SHELL_H/2:.2f},{PCB_T:.2f}]) '
                     f'rotate([90,0,0]) import("{ins}");')
    return "\n".join(lines)


def render(name, cam, explode):
    s = os.path.join(B, f"_fit_{name}.scad")
    open(s, "w").write(scad(explode))
    out = os.path.join(B, f"fit_{name}.png")
    subprocess.run(["openscad", "-o", out, "--imgsize=1200,800", "--colorscheme=Tomorrow",
                    f"--camera={cam}", "--autocenter", "--viewall", s], capture_output=True)
    print("  ->", out, "OK" if os.path.exists(out) else "FAILED")


def render_pop():
    """populated board (tscircuit, with component bodies) under the spacer frame — connector /
    display protrusion + clearance vs the shell openings."""
    p = os.path.join(B, "pcb_pop.stl")
    if not os.path.exists(p):
        return
    f = os.path.join(B, "frame.stl")
    lines = ['$fn=48;', f'color([0.10,0.42,0.20]) import("{p}");']
    if os.path.exists(f):
        lines.append(f'%color([0.6,0.62,0.66]) translate([0,0,{PCB_T:.2f}]) import("{f}");')  # ghosted
    s = os.path.join(B, "_fit_pop.scad"); open(s, "w").write("\n".join(lines))
    out = os.path.join(B, "fit_pop.png")
    subprocess.run(["openscad", "-o", out, "--imgsize=1200,800", "--colorscheme=Tomorrow",
                    "--camera=0,0,0,62,0,25,400", "--autocenter", "--viewall", s], capture_output=True)
    print("  ->", out, "OK (populated: component bodies)" if os.path.exists(out) else "FAILED")


def main():
    os.makedirs(B, exist_ok=True)
    expl = float(sys.argv[1]) if len(sys.argv) > 1 else 6.0
    print(f"fit-check render (explode={expl}mm):")
    render("iso", "0,0,0,58,0,22,420", expl)      # exploded iso (bare board layers)
    render("top", "0,0,0,0,0,0,420", 0.0)          # top-down alignment (no explode)
    render_pop()                                   # populated board (component bodies) if present


if __name__ == "__main__":
    main()

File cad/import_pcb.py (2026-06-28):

"""import_pcb.py — bring the board into the cad assembly as an STL, two ways.

Dispatches on the source extension:
  *.kicad_pcb  -> kicad-cli STEP (the ROUTED board, but BARE — tscircuit footprints carry no
                  KiCad 3D models). Y-mirrored (KiCad is Y-down). -> build/pcb.stl
                  Clean flat plate — best for layer registration (outline/cutouts/screws vs frame).
  *.tsx        -> tsci export -f step (the POPULATED board — 30 cad_components with real EasyEDA
                  3D models from the CDN: USB-C, ESP32, amp + generic passives). Already centered
                  + Y-up, no flip. -> build/pcb_pop.stl
                  Carries component BODIES — best for connector/display protrusion + clearance.

Both are centered on the cassette origin. Run after each place/route pass:
    python3 import_pcb.py ../pcb/index.circuit.kicad_pcb   # bare, for the stack
    python3 import_pcb.py ../pcb/index.circuit.tsx         # populated, for connector bodies
"""
import subprocess, os, sys
from build123d import import_step, export_stl, Pos, mirror, Plane
import machine_params as M

HERE = os.path.dirname(os.path.abspath(__file__))
B = os.path.join(HERE, "build")
STEP = "/tmp/_pcb_fit.step"


def export_step(src):
    src = os.path.abspath(src)
    if src.endswith(".tsx"):
        pcb = os.path.join(HERE, "..", "pcb")
        env = {**os.environ, "PATH": f"{os.environ['HOME']}/.bun/bin:{os.environ.get('PATH','')}"}
        tsci = os.path.join(pcb, "node_modules", ".bin", "tsci")
        # tsci mangles an absolute -o; write relative to pcb/ (the copperpour async warning is benign)
        subprocess.run([tsci, "export", src, "-f", "step", "-o", "build/_pop.step"],
                       cwd=pcb, env=env, capture_output=True, text=True, timeout=240)
        p = os.path.join(pcb, "build", "_pop.step")
        return p if os.path.exists(p) else None
    subprocess.run(["kicad-cli", "pcb", "export", "step", "--subst-models", "--no-dnp",
                    "-o", STEP, src], capture_output=True, text=True)   # nonzero on warnings; trust the file
    return STEP if os.path.exists(STEP) else None


def main():
    src = sys.argv[1] if len(sys.argv) > 1 else os.path.join(HERE, "..", "pcb", "index.circuit.kicad_pcb")
    populated = src.endswith(".tsx")
    os.makedirs(B, exist_ok=True)

    step = export_step(src)
    if not step:
        sys.exit(f"3D export produced no file for {src}")
    s = import_step(step)
    bb = s.bounding_box()
    cx, cy = (bb.min.X + bb.max.X) / 2, (bb.min.Y + bb.max.Y) / 2
    s = Pos(-cx, -cy, -bb.min.Z) * s          # center XY, lowest point -> z=0
    if not populated:
        s = mirror(s, Plane.XZ)               # KiCad Y-down -> cad Y-up (tscircuit is already Y-up)

    out = os.path.join(B, "pcb_pop.stl" if populated else "pcb.stl")
    export_stl(s, out)
    b = s.bounding_box()
    print(f"{'populated (tscircuit, +bodies)' if populated else 'bare (kicad, routed)'}: "
          f"{b.size.X:.1f} x {b.size.Y:.1f} x {b.size.Z:.2f} mm -> {out}")
    if not populated:
        dx = b.size.X - M.SHELL_W
        print(f"  outline vs shell {M.SHELL_W}x{M.SHELL_H}: "
              f"{'MATCH' if abs(dx) < 1 else f'dX={dx:+.1f}mm overhang'}")


if __name__ == "__main__":
    main()

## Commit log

2026-06-27 flexisette: flex-PCB cassette multimedia object (CAD + PCB + display)
    Parametric cassette-shaped board: ESP32-S3 + SSD1306 OLED in the tape window +
    MAX98357A speaker amp + LiPo/USB-C. Includes build123d CAD derived from vendor
    cassette STLs, the tscircuit PCB (modular subcircuits + place->route->measure
    tooling + per-fab DRC rule sets), and the 128x64 tape-winding animation.
    [alpha-side-1.stl, alpha-side-2.stl, assembled.FCStd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]
2026-06-27 pcb: gitignore KiCad cruft; remove committed autosave/lock/stray exports
    Also: headless Freerouting->KiCad SES injector (scripts/apply_ses.py) — WIP,
    union-find net assignment; not yet clean (GND-pour interaction).
    [power.circuit.kicad_pcb]
2026-06-27 pcb: fabbable cassette floorplan + headless IPC routing pipeline
    Re-floorplan respecting ALL cassette cutouts (OLED window / 2 reel holes /
    4 screw holes / bottom head-notch): spread the blocks across the board,
    narrow the ESP32 column to fit beside the reel, and drop the now-redundant
    breakout headers (J_IO/J_I2S/J_PWR) + reset/boot buttons (native-USB esptool
    programming). All three placement gates pass: every part inside the outline,
    0 courtyard overlaps, ~1 unrouted with the holes kept out. Routed via the IPC
    pipeline (Freerouting -> kipy inject) with a GND pour; net fragments reconciled.
    New place->route tooling (also in the global pcb-layout skill):
    route.sh, merge_nets.py, add_cuto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
    [index.circuit.kicad_pcb]
2026-06-27 pcb: block-level autoplacer (autoplace.mjs) + unit tests
    Simulated-annealing autoplacer for the subcircuit blocks: reads circuit.json
    (block bboxes + cutouts + outline + inter-block connectivity) and minimises
    HPWL under hard penalties for the three placement gates (block-block overlap,
    block-on-cutout, block-outside-outline via point-in-polygon — respects the
    head-notch). --scramble + restarts, --lock for edge connectors, --write to
    apply. Pure geometry/cost/anneal/extract are exported + unit-tested
    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
2026-06-27 pcb: OLED as a placed part + keepout-respecting route
    - Add the 0.96" SSD1306 OLED MODULE as a real placed part (custom footprint:
    4-pin header on solid board below the window + a 27x27mm body silkscreen
    outline over the window, on the BACK layer) so the drawing shows/reserves
    where it physically sits behind the tape window. Replaces the J_OLED header;
    buses route to OLED.SCL/SDA/VCC/GND.
    - Re-route with cutout keepouts active and inject the keepout-respecting SES:
    geometric check confirms 0 track/via inside the reels or window (was crossing).
    - outline-check: ALLOW_IN_CUTOUT (default "OLED") so a display intentionally
    behind a window isn't flagged.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
    [index.circuit.kicad_pcb]
2026-06-28 pcb: fix window keepout + JLC DRC rules -> DRC 216->23 cosmetic
    - add_cutout_keepouts: poly regex missed the window (newline before pts close
    paren) so it was never kept out; one trace crossed it. Fixed -> 7 interiors
    detected (window + 2 reels + 4 screws), re-routed, segment check = 0 copper
    inside any hole.
    - apply_fab_rules.py: set .kicad_pro DRC to JLCPCB mins (clearance 0.127,
    copper-edge 0.2, min-text 0.25) + ignore non-fab cosmetic checks
    (lib_footprint, silk, back-text). Cosmetic DRC 216 -> 23; real tail =
    3 shorts + 13 unconnected.
    - apply_ses_ipc: drop the endpoint-snap experiment (added crossings/shorts).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
    [index.circuit.kicad_pcb]
2026-06-28 pcb+cad: U1 re-floorplan (fix edge spills) + 3D fit-check + JLCPCB fab tooling
    - pcb: move MCU off the left board edge (-40 -> -38) and clean re-route;
    obstacle-aware surgical short fixes -> 0 shorts / 0 crossings / 0 edge-over-cut
    - drc_check: promote copper AT/OVER the board cut (edge clearance <= 0.05mm) to a
    real blocking class; it was hidden inside the cosmetic bucket
    - cad/import_pcb.py + render_fit.py: bring the routed board into the printed-cassette
    assembly as STL -- bare KiCad board for layer registration, populated tscircuit
    board (component bodies from the CDN models) for connector clearance; `make fit`
    - gen_bom_cpl.py + `make fab`: JLCPCB gerber+drill zip and assembly B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
    [index.circuit.kicad_pcb]
2026-06-28 pcb: round-trip floorplan loop (positions-as-data) for fast pre-routing iteration + variants
    - sync_positions.py / apply_placement.py: round-trip part positions between a KiCad
    board and pcb/placement/<variant>.json (tscircuit-centred frame). Faithful round-trip
    verified (30/30 parts, 0 drift). Handles both fresh-tsci and KiCad-saved footprint
    formats (unquoted vs quoted layer; first-(at) in block).
    - make place/sync/variant: drag+rotate parts in KiCad against the ratsnest on a
    throwaway floorplan board, sync back to data; fork placement/<release>.json for
    per-drop board variants. route.sh applies the saved placement after export.
    - pcb/placement/default.json: the current working f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
2026-06-28 pcb: auto-untangle — part-level rotation pass to shorten the ratsnest pre-routing
    scripts/untangle.mjs: holds positions fixed, rotates each part to the 0/90/180/270
    that minimises its SIGNAL nets' wirelength (power/ground dropped by fanout — poured),
    iterating to convergence. Every rotation is GATE-CHECKED (won't push a part off the
    outline or onto a cutout). ~14% shorter signal wirelength, 11 parts reoriented on
    flexisette. Writes straight to placement/<variant>.json -> seeds the round-trip loop:
    make untangle -> make place -> route. Pure core tested (tests/untangle.test.mjs, 7 cases).
2026-06-28 docs: placement-constraints design + roadmap (planning only)
    - placement-constraints.md: proposed per-part constraint layer (lock / move-radius /
    rotate-set / edge-anchor) the placers + round-trip respect; additive, opt-in, reads
    KiCad's native locked flag via sync. Phased MVP. NOT built.
    - roadmap.md: known gaps (incl. the round-trip placement -> routing DSN gap found while
    validating untangle), production-clean pass items, and grounded SOTA placement
    directions (crossing-aware objective, force-directed seed) — cheapest-first.
    Untangle validated: rotation-only, 51 -> 36 ratsnest crossings (29% fewer),
    943 -> 815 mm signal wirelength (14% shorter); working board untouched.
    Co-Aut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
2026-06-29 cad: model the 0.96" OLED + show its screen through the tape window in the fit render
    tscircuit can't draw the SSD1306 module (no CDN 3D model), so cad/oled.py models it (blue
    module PCB + dark glass screen + 4-pin header). render_fit.py seats it behind the board at
    the window — the screen reads as the dark rectangle through the cassette tape window, and
    explodes down with the stack. `make fit` builds it. The render also surfaced a real fit nit:
    the printed panel's window is a touch taller than the board cutout (green sliver above the screen).
2026-06-29 cad: merge the OLED into tscircuit's GLB + `make show` to open artifacts
    - merge_oled_glb.py: tscircuit's `tsci export -f glb` omits the SSD1306 (no CDN 3D
    model); this drops cad/build/oled.stl into the GLB at the window (rotate Z-up->Y-up,
    seat behind the board) -> pcb/build/3d/flexisette_oled.glb (45 -> 47 meshes).
    - make show: open the fit renders + print the GLB/STL/`tsci dev` paths (artifacts live
    in gitignored build/ dirs — real files, just not committed).
2026-06-29 render: add the OLED to the Blender full-assembly render
    render_assembly.py now seats cad/oled.py's module + screen behind the board at the tape
    window, so a re-render (on the GPU box) shows the complete stack: real routed board +
    printed panel/frame/insert + OLED. (Already switched to the real pcb.stl earlier.)
2026-06-29 docs: comprehensive documentation set (docs/) for the whole project
    A navigable docs/ set covering every subsystem, written from the actual source:
    - architecture.md — the big picture: three subsystems (PCB/placement/CAD), the
    fit-check seam, data flow, the four coordinate frames, repo map, principles
    - pcb-toolchain.md — modular subcircuits + the tscircuit->KiCad place->route->IPC pipeline
    - placement.md — positions-as-data round-trip, auto-untangle, autoplace, gates
    - cad-enclosure.md — the build123d cassette shell (sandwich, machine_params, parts, assembly)
    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
2026-06-29 docs: feature-ideas TODO — tape-deck playback (hub encoder + head coil) + speaker
    - Tape-deck playback (planned): head-emulation coil in the insert induces audio into a
    deck's playback head (cassette-adapter trick reversed) + a hub-rotation encoder syncs
    playback rate to the deck's transport, so any deck can "play" the flexisette speed-coupled.
    Open questions on encoder type, coil design/EQ, free-spinning hubs, firmware captured.
    - Bass-reflex micro-speaker (in design): slim oval driver through the 24x6 head slot,
    folded port, ~6-8 cm3 in the insert. Notes the contention with the head coil for insert space.
2026-06-29 sim: bass-reflex micro-speaker Thiele-Small model (ngspice + analytic)
    sim/speaker_reflex/reflex.py: acoustical equivalent circuit of the insert speaker (driver +
    6cm3 box + folded slot port). Box = compliance Cab, folded port = mass Lmap+Rap — the enclosure
    is IN the model. ngspice solve verified against an independent numpy complex-impedance solve
    (0.00% error); sealed Fc=1137Hz and the vented twin-hump impedance (Fb dip ~412Hz) check out;
    radiated sum is Ud-Up (front+port cancel below Fb -> acoustic short).
    Findings (representative driver): at 6cm3 the box is ~4x undersized so ported ~= sealed
    (small Fb bump, steeper rolloff below, ~0dB net) -- decide sealed-vs-port on the REAL driver'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
2026-06-29 sim: re-point speaker model to SEALED face-firing PUI AS01808AO + Vb sweep
    Decision: face-firing (cassette is 9mm thick -> forward-firing micro doesn't fit), sealed
    enclosure. Re-pointed the verified T-S model at the PUI AS01808AO (Fs=320Hz published; Vas/Qts
    ESTIMATED, flagged) and made it a sealed back-volume sweep. Findings: the real driver's low Fs
    drops the sealed knee to ~450-550Hz (real low-mid lift vs the 1.1kHz placeholder); Qtc is high
    (~1.3-2.0) on the estimated Qts -> measure before locking (boomy vs flat hangs on it); more
    back-volume always helps (carve ~10-12cm3); excursion-limited to ~250mW clean -> ~70dB@1m.
    ngspice vs analytic 0.00%.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
